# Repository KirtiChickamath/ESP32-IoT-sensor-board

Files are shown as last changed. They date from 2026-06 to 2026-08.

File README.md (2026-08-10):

# ESP32 IoT Sensor Board

A 4-layer IoT PCB designed in KiCad 9 as part of the **Advanced PCB Design with KiCad 9** course by Dr. Peter Dalmaris.

## Overview

This board is a medium-complexity IoT development platform built around the ESP32-C3 microcontroller. It includes power management, wireless connectivity, storage, and environmental sensing. All on a compact 4-layer PCB.

## Features

- ESP32-C3-WROOM-02 — WiFi and Bluetooth
- USB-C input with ESD protection (USBLC6) and polyfuse
- LiPo battery management with power-path (MCP73871)
- 3.3V LDO voltage regulator (LM1117)
- USB-to-UART bridge (CP2102N) for programming and debugging
- SPI flash memory (W25Q32)
- MicroSD card slot (SPI mode)
- BME280 — temperature, humidity, and pressure (I2C)
- Ambient light sensor (TEMT6000)
- Microphone with preamplifier (MAX4466)
- Status LEDs — power good, charging, charged
- Boot and EN tactile switches
- GPIO and I2C breakout header
- Test points for SPI signals

## Layer Stackup

 Layer - Purpose 

 Top copper - L1 -  Components and signal routing 
 Inner 1 - L2 - Ground plane 
 Inner 2 - L3 - 3.3V power plane 
 Bottom copper - L4 -  Additional signal routing 

## Communication Interfaces

 Interface - Connected To 

 SPI - Flash memory, SD card 
 I2C - BME280, OLED header 
 UART - CP2102N (via USB) 
 ADC - Light sensor, microphone 

## Schematic

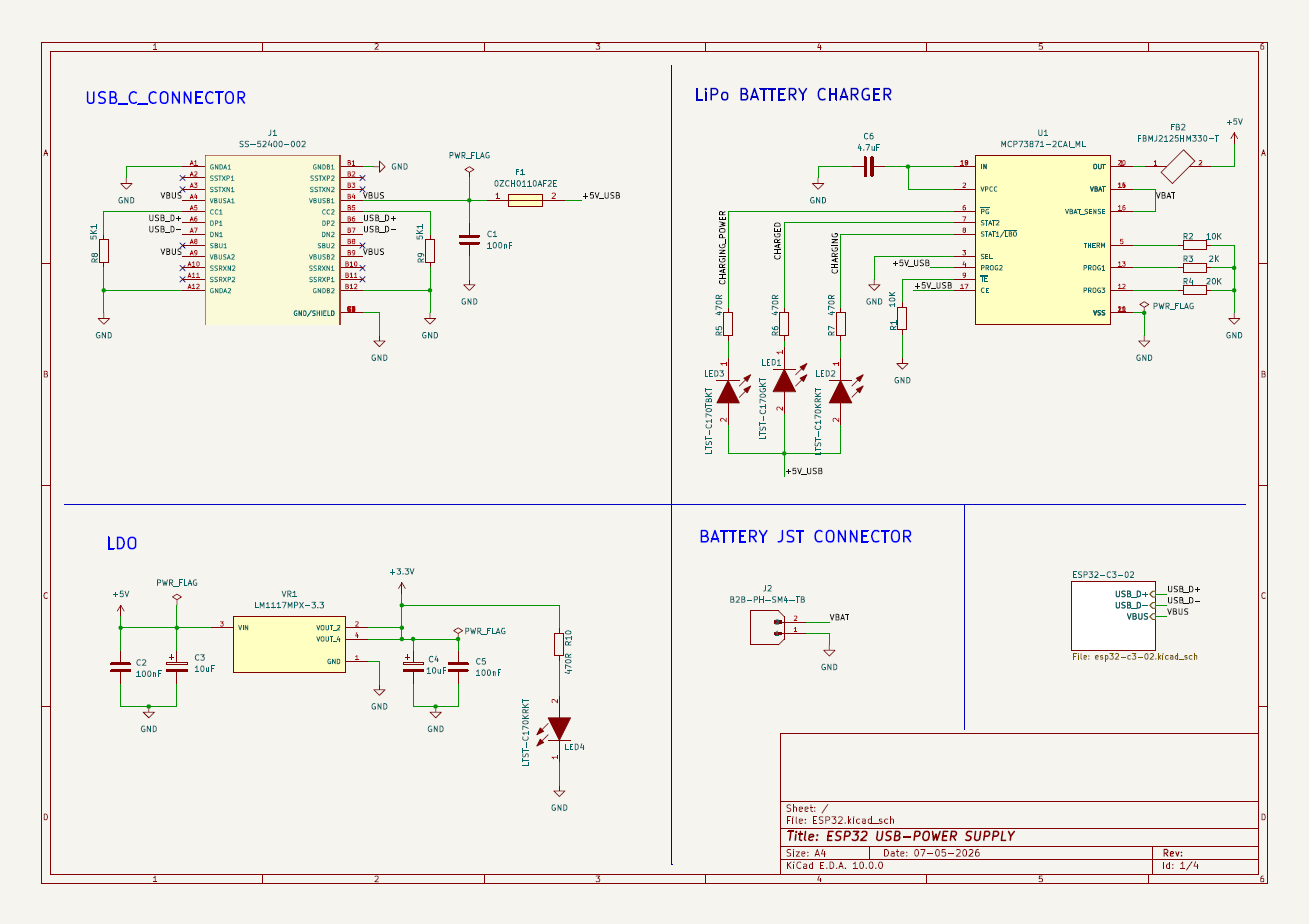
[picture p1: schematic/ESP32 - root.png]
Root

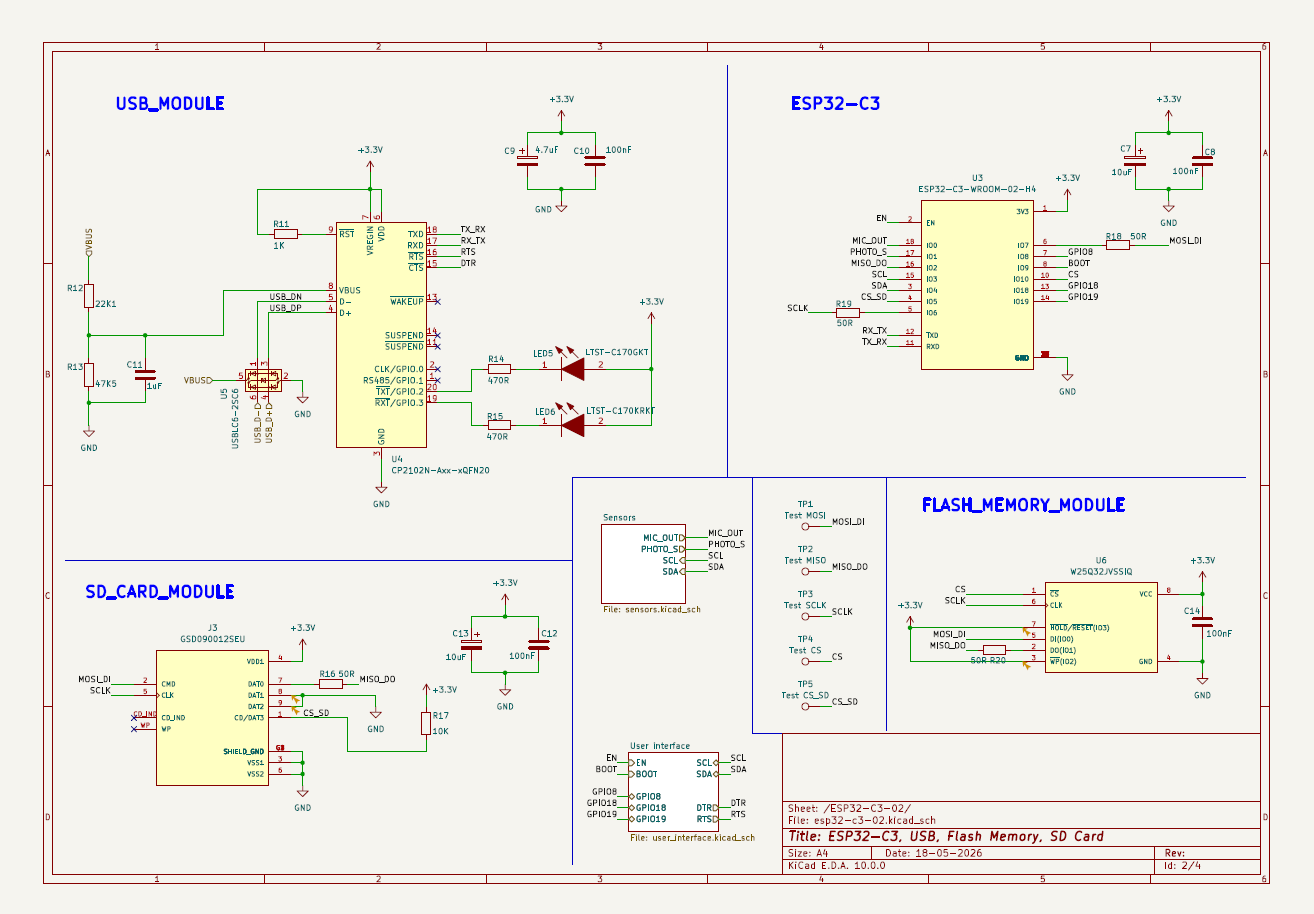
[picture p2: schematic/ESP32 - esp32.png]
ESP32

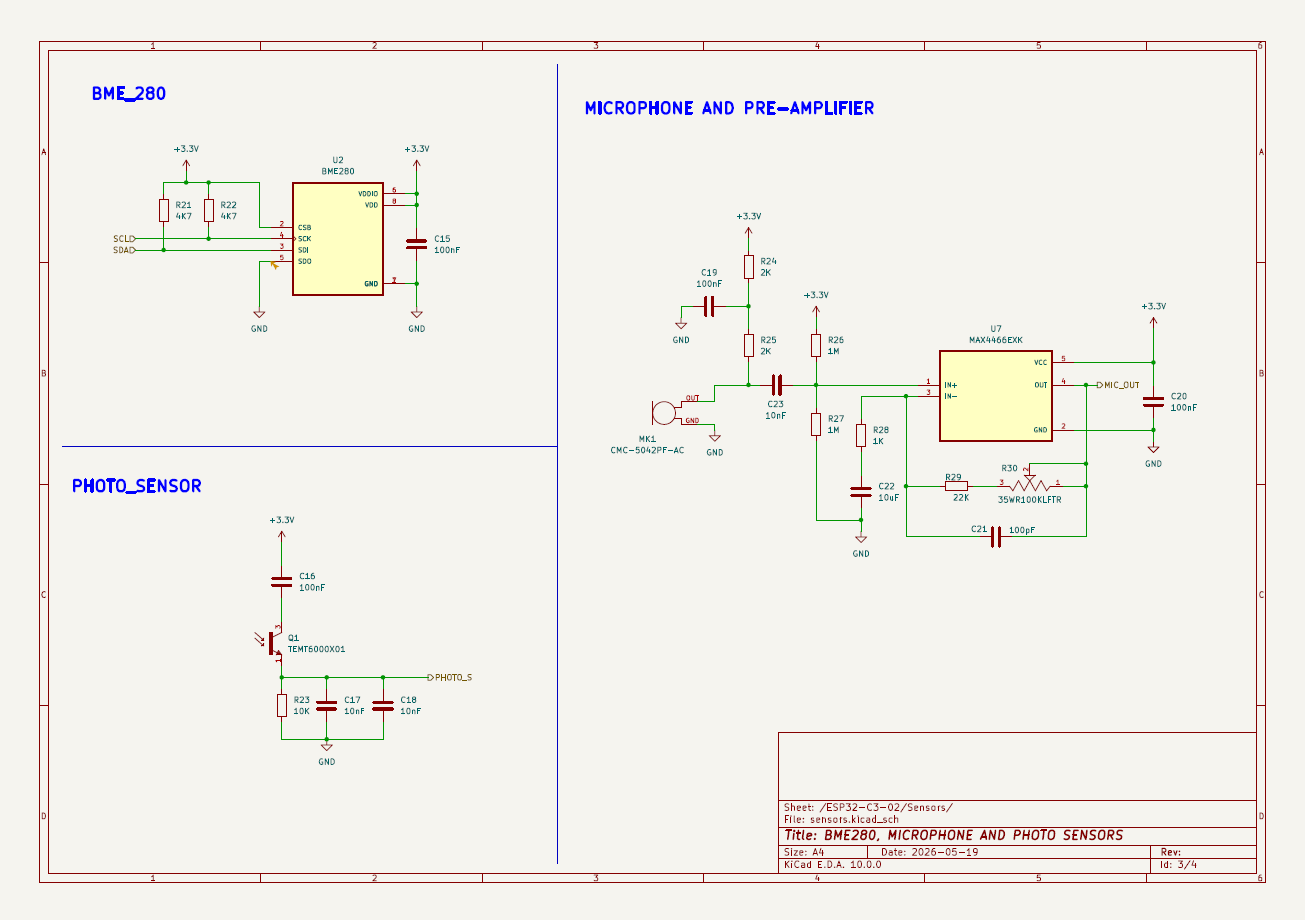
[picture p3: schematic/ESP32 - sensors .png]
Sensors

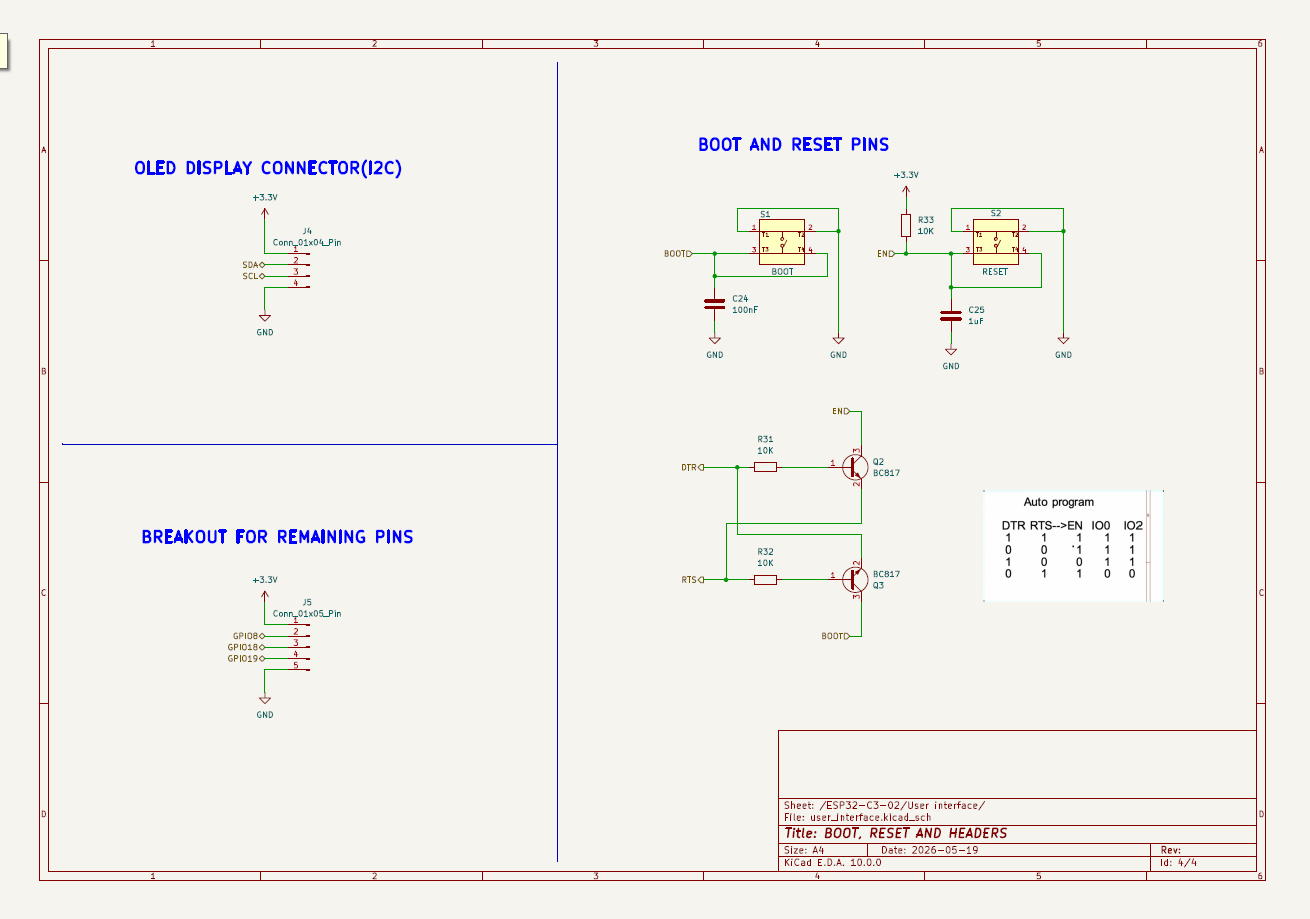
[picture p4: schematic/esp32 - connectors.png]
Connectors

---

## PCB Layout

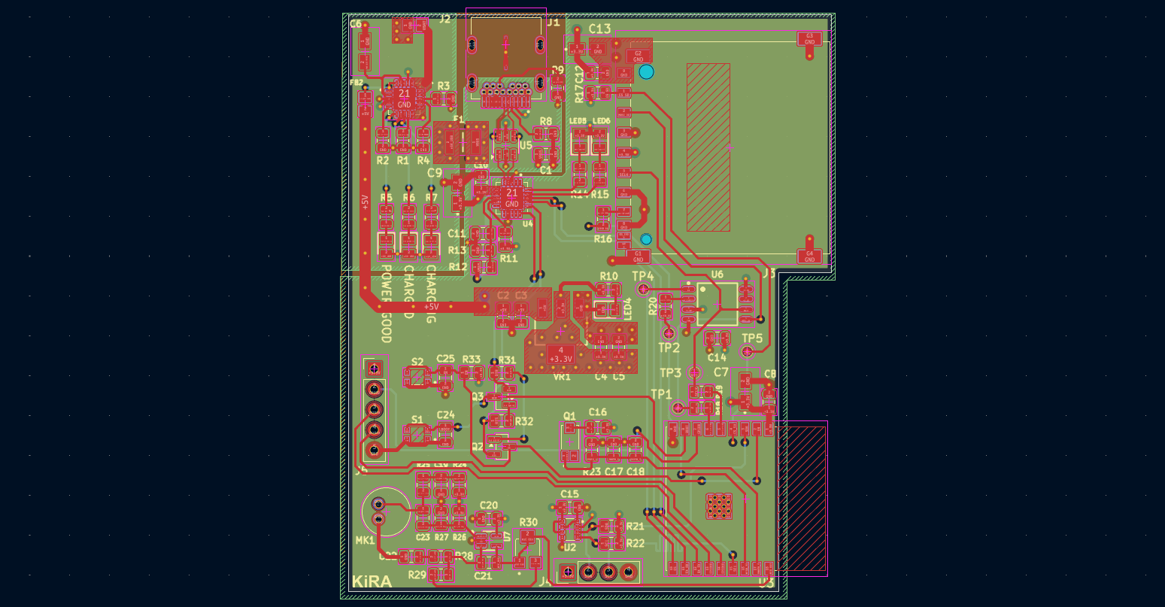
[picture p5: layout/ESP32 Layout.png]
Layout


## 3D View

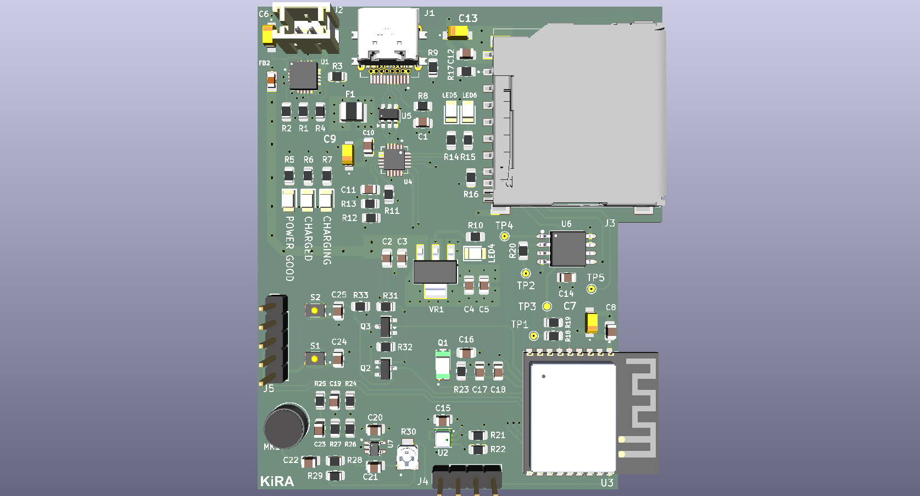
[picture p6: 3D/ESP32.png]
3D View


## Tools Used

- KiCad 
- HQDFM

---

## Course Reference

**Advanced PCB Design with KiCad 9**  
Instructor: Dr. Peter Dalmaris  
Platform: Udemy

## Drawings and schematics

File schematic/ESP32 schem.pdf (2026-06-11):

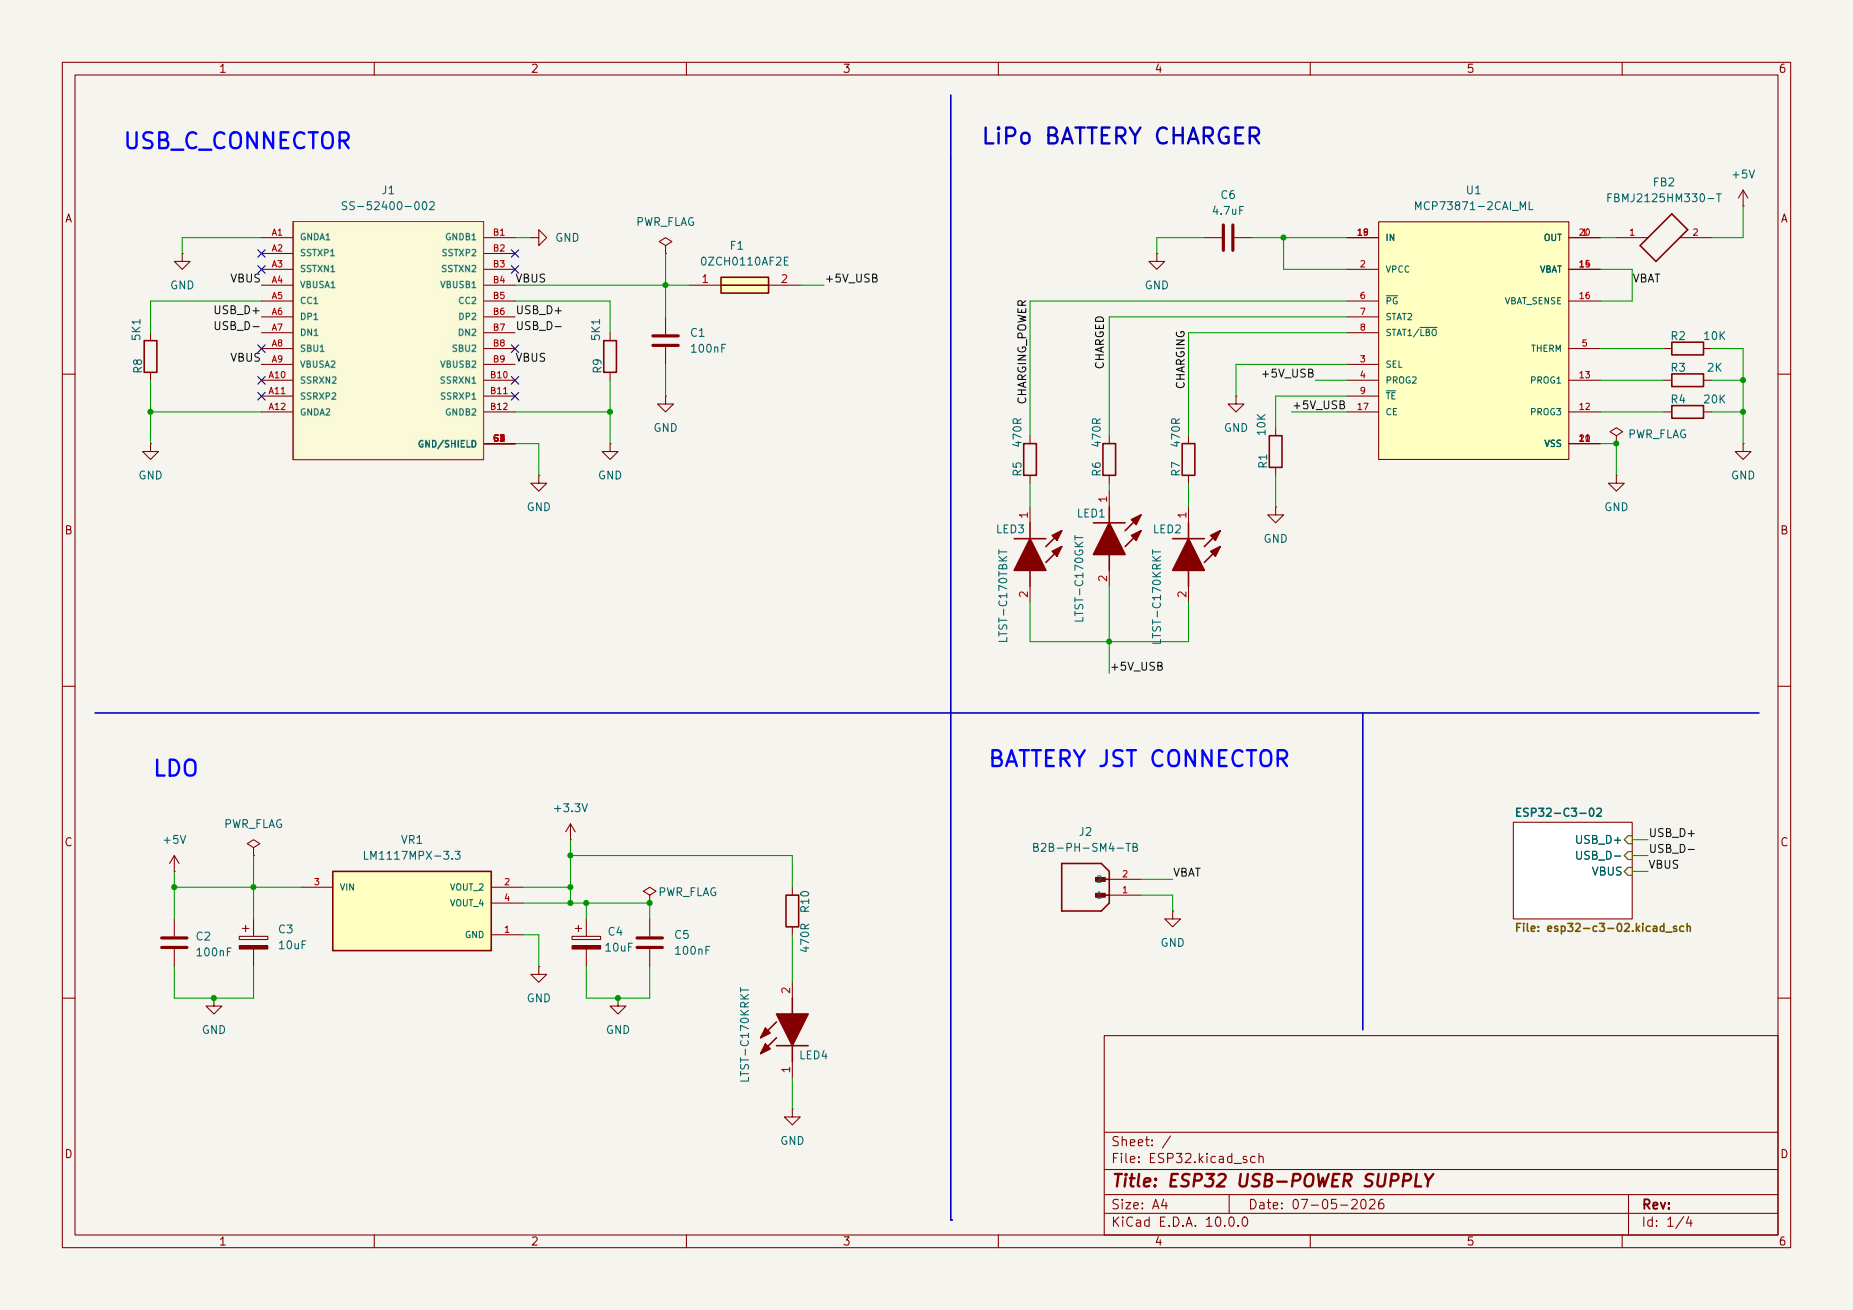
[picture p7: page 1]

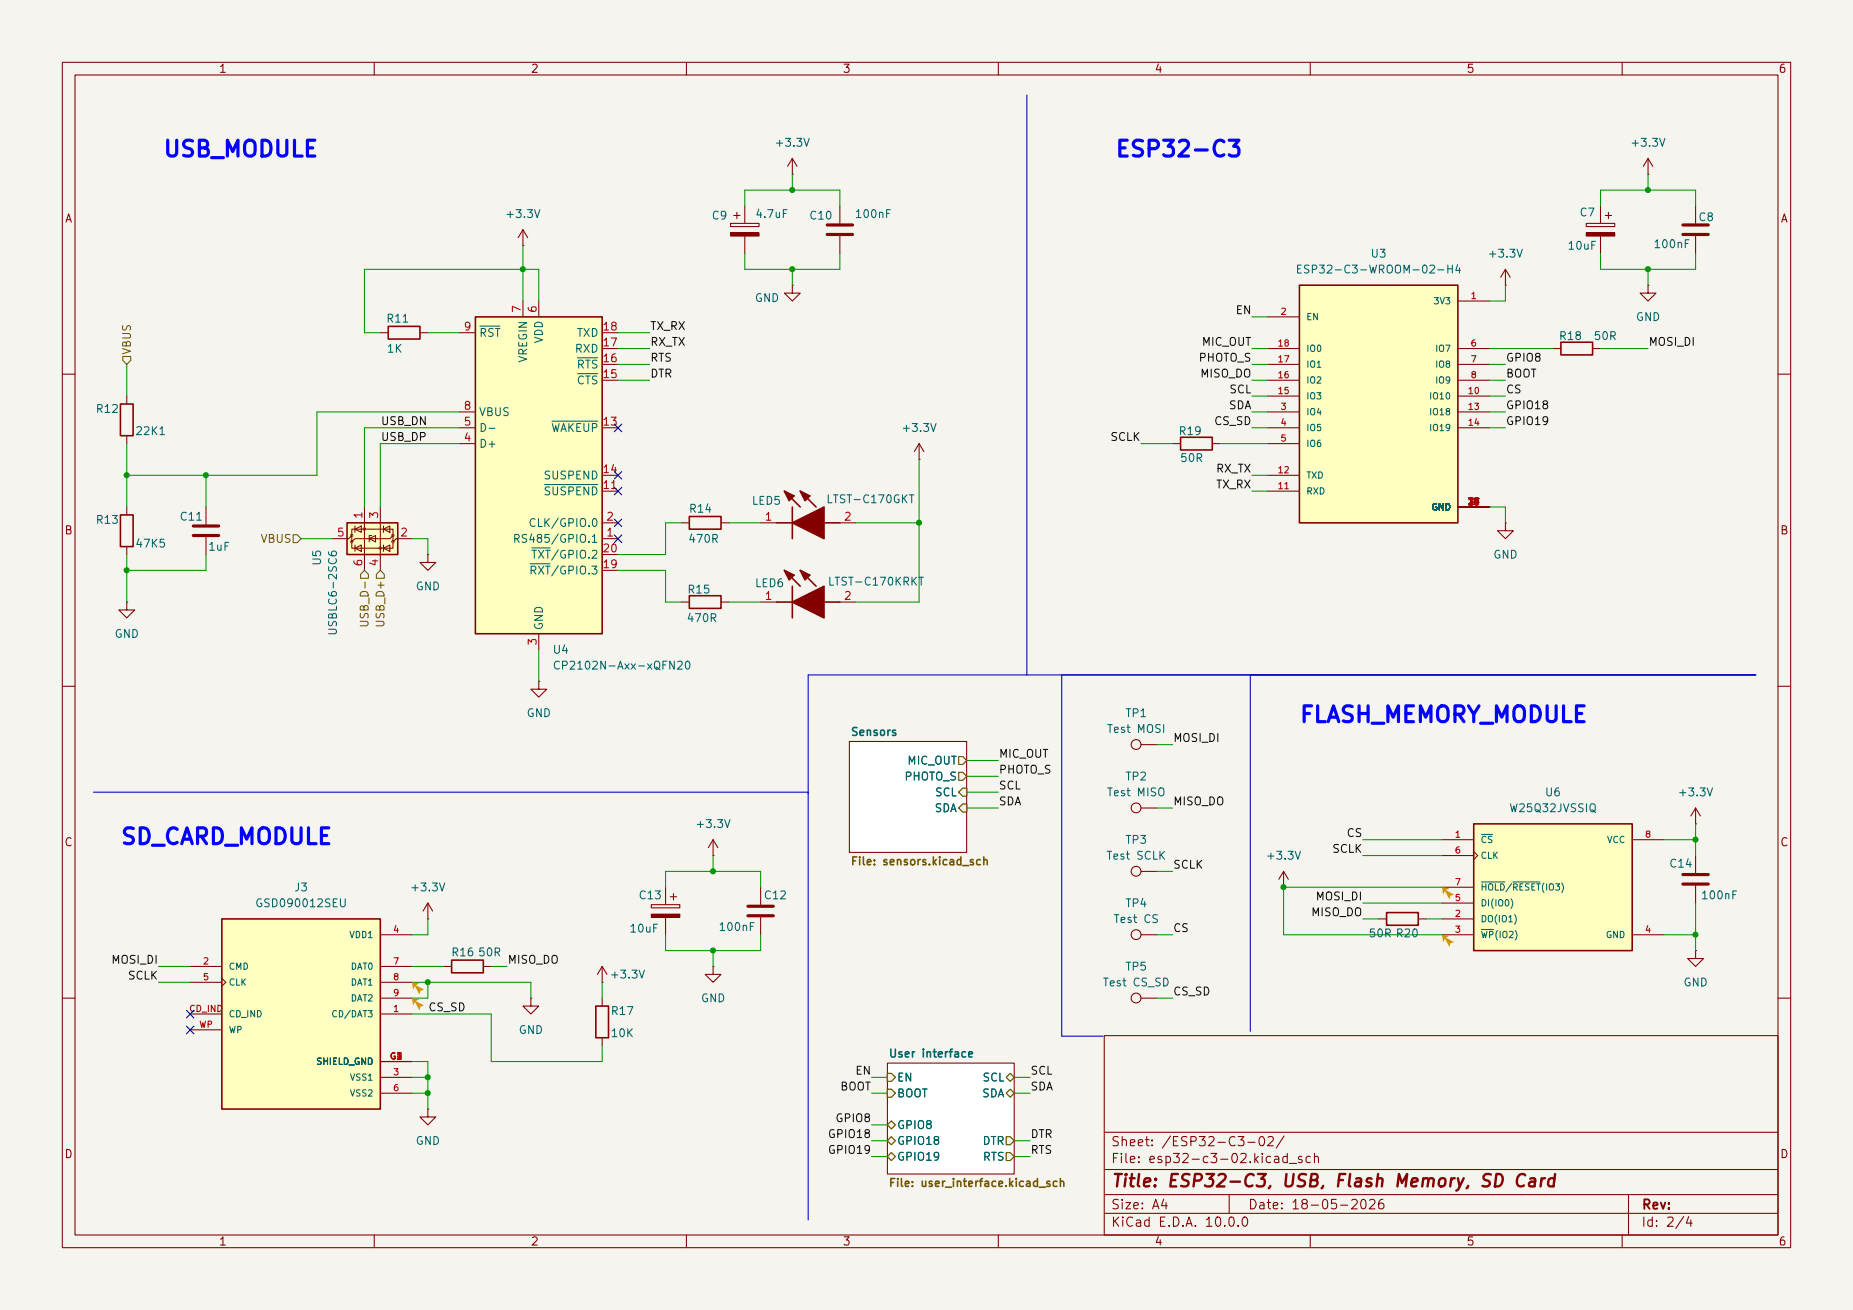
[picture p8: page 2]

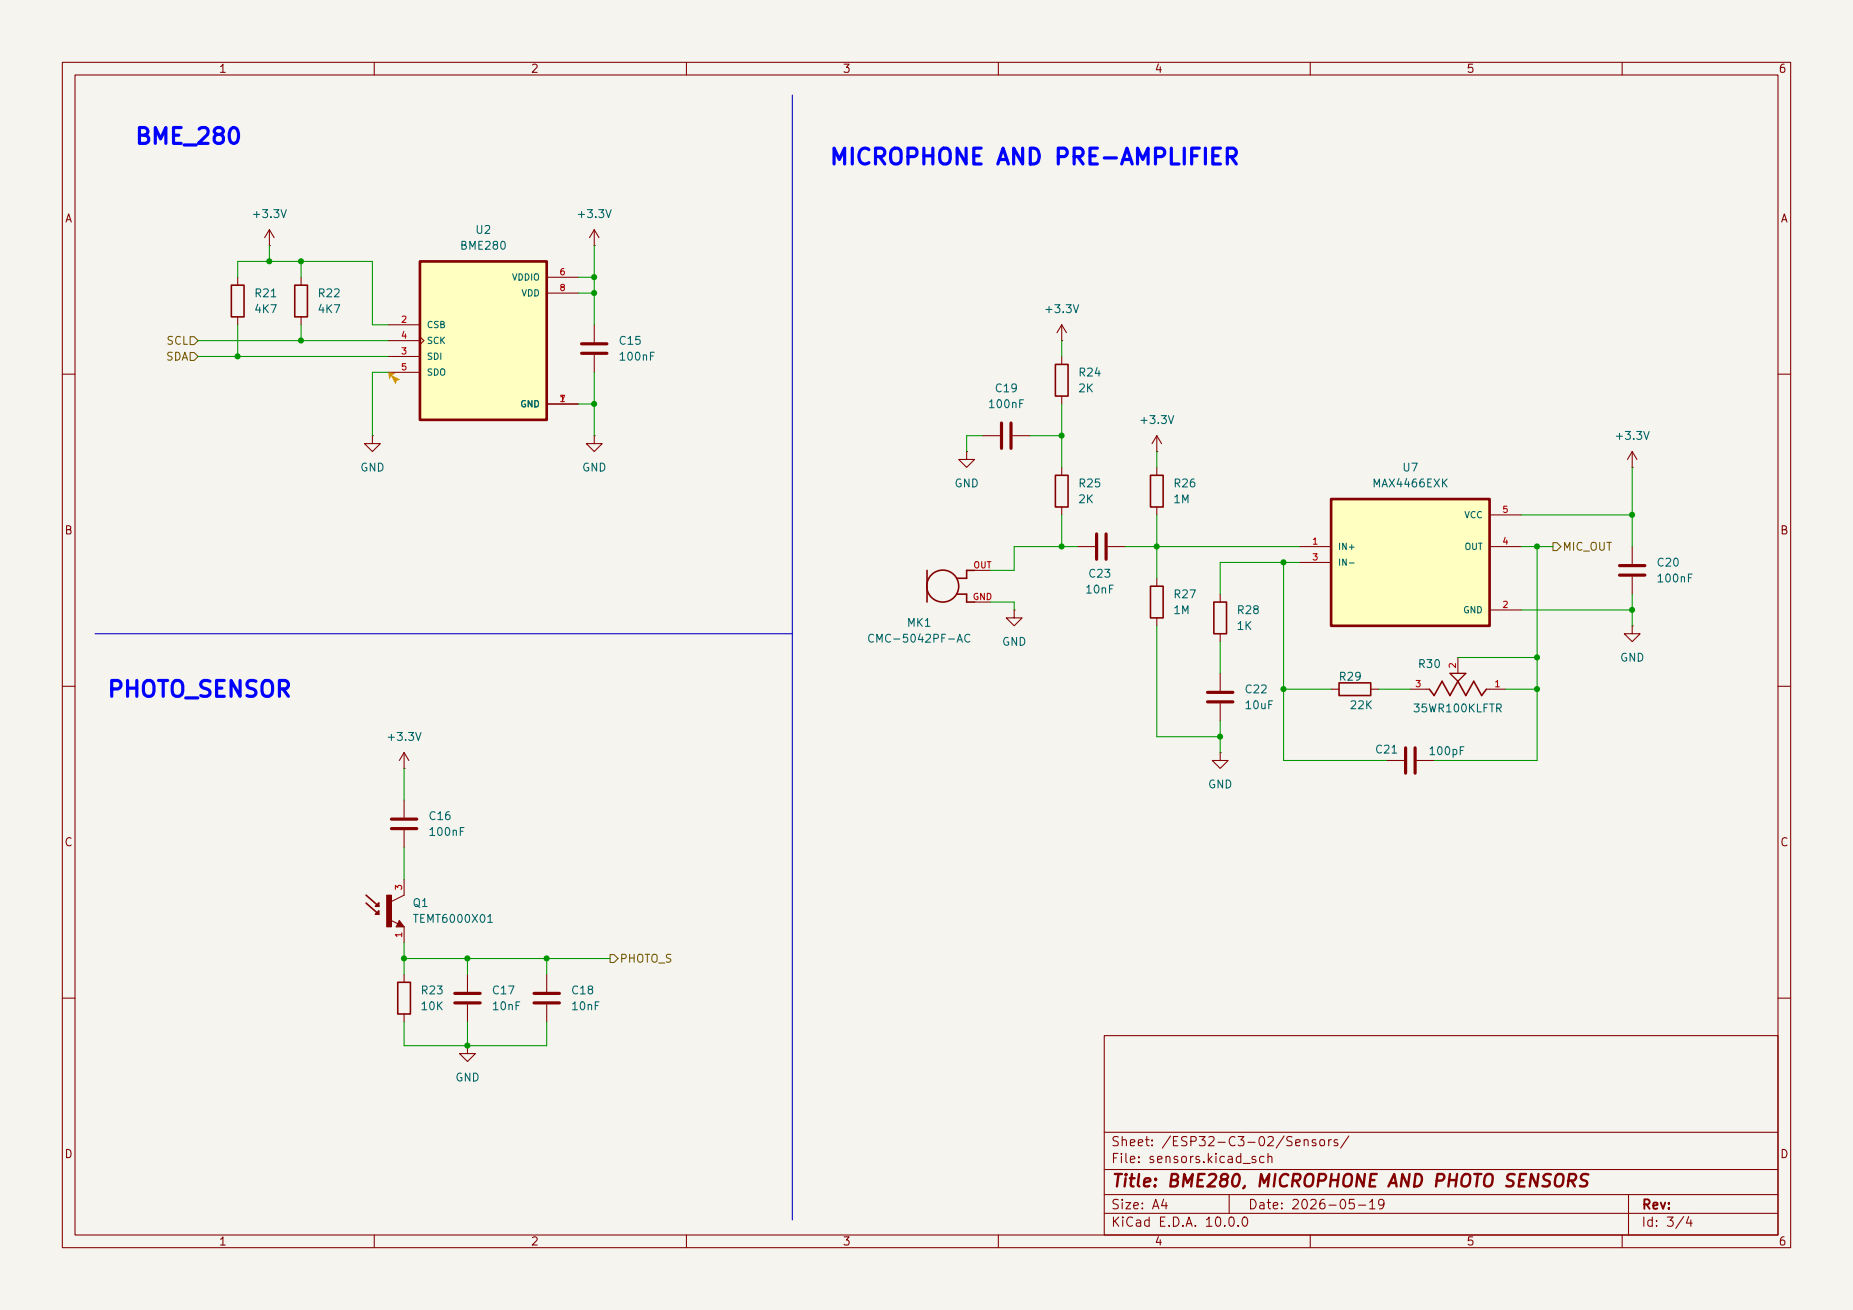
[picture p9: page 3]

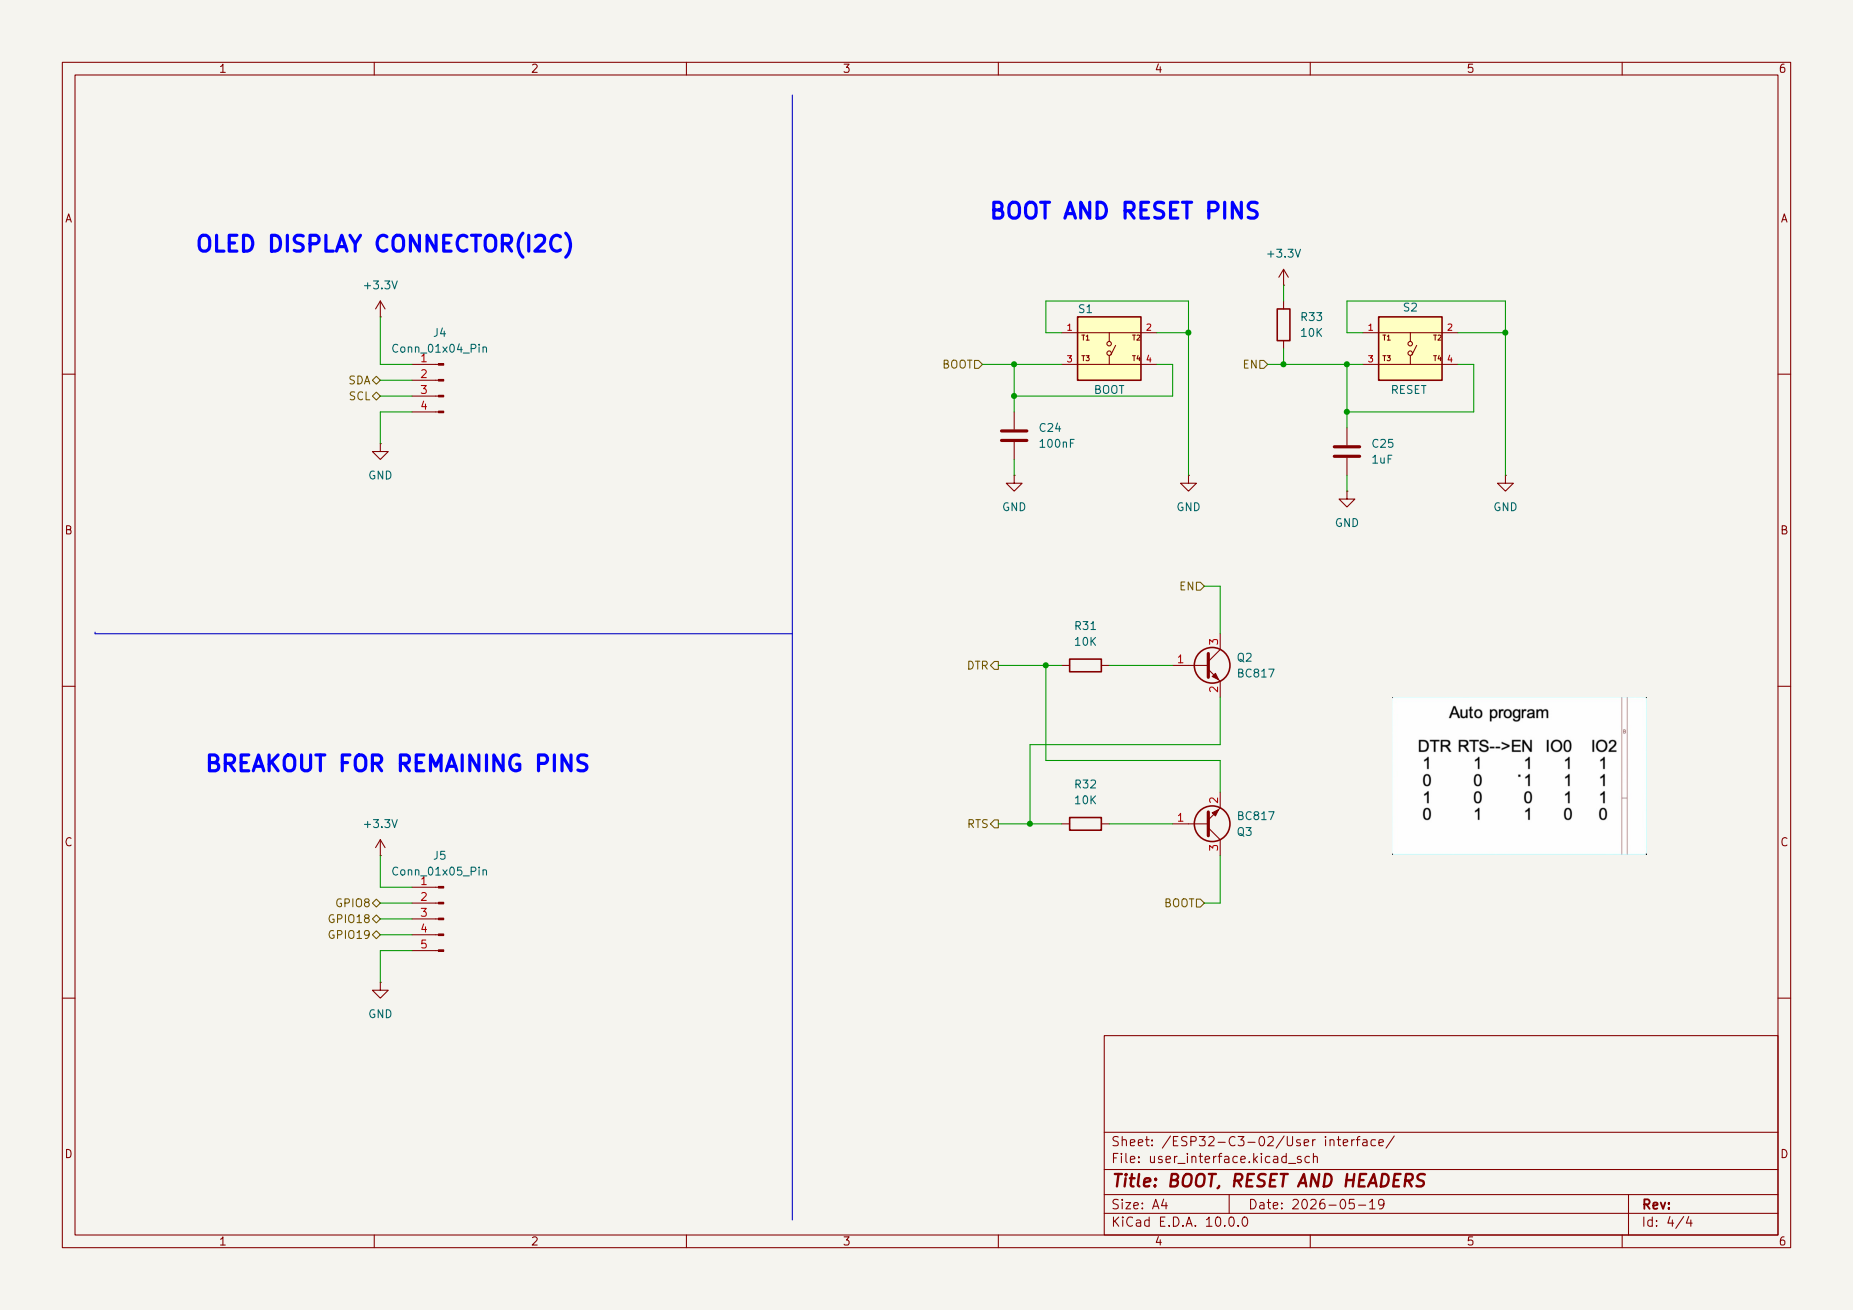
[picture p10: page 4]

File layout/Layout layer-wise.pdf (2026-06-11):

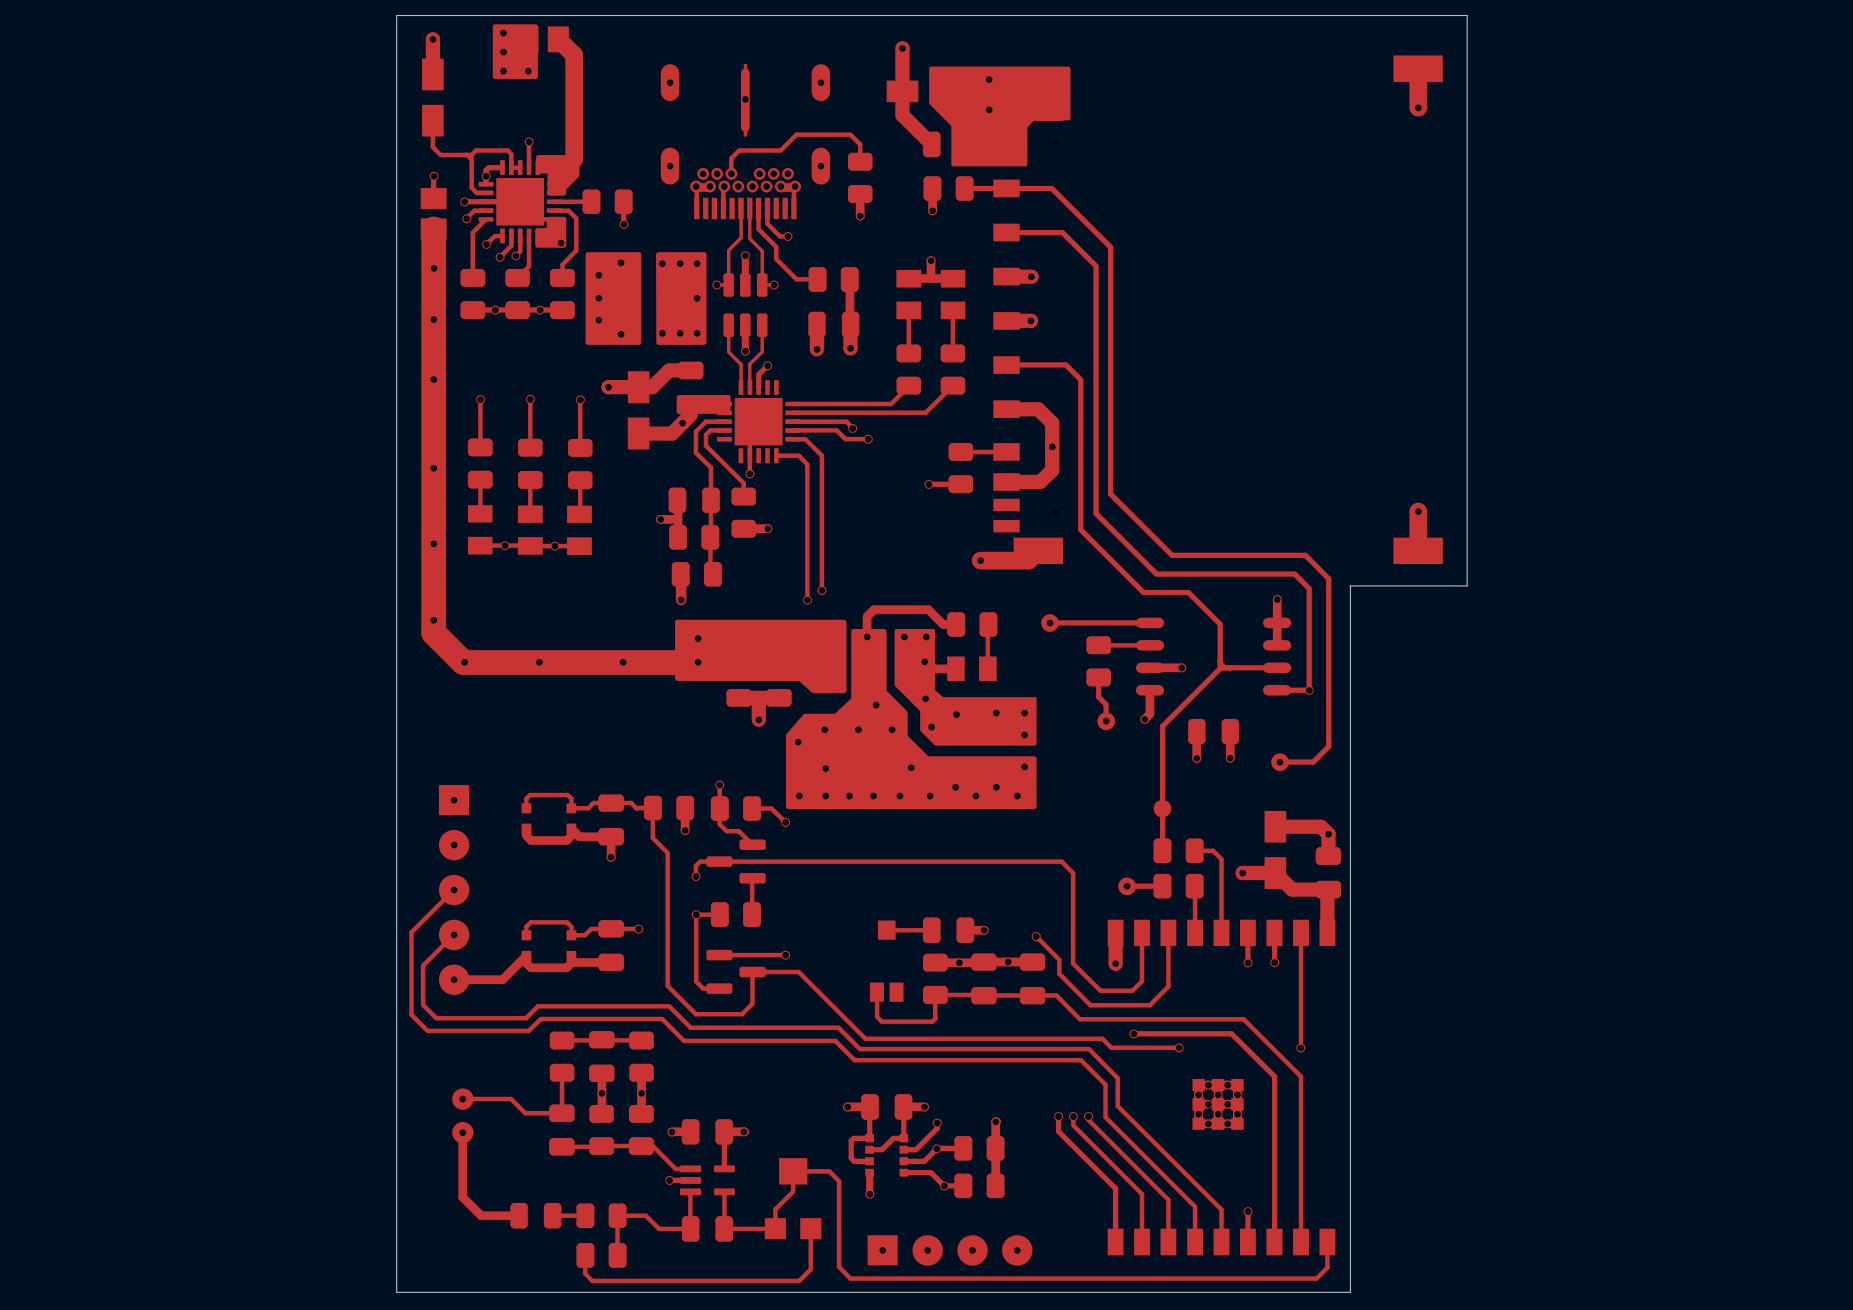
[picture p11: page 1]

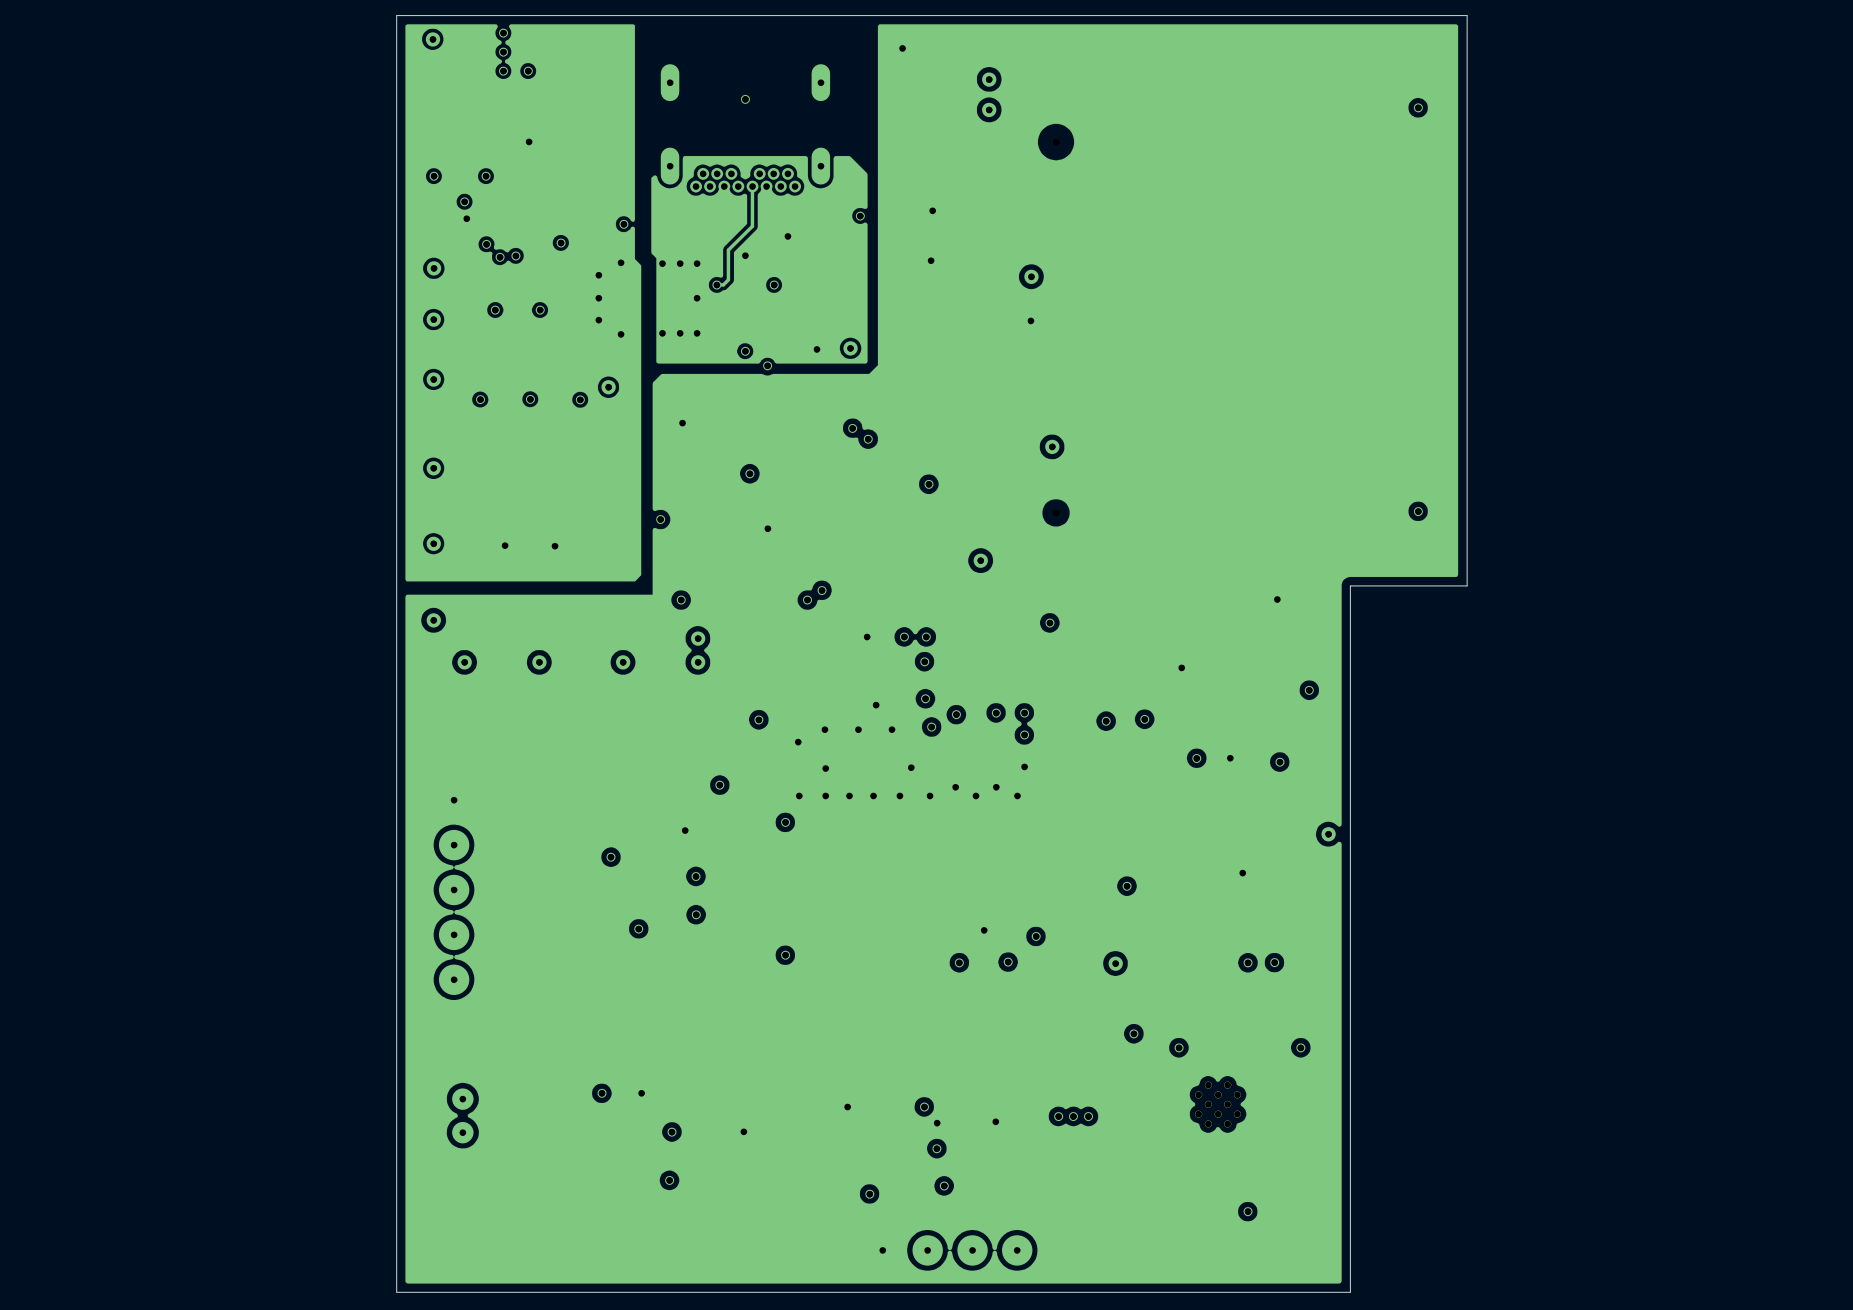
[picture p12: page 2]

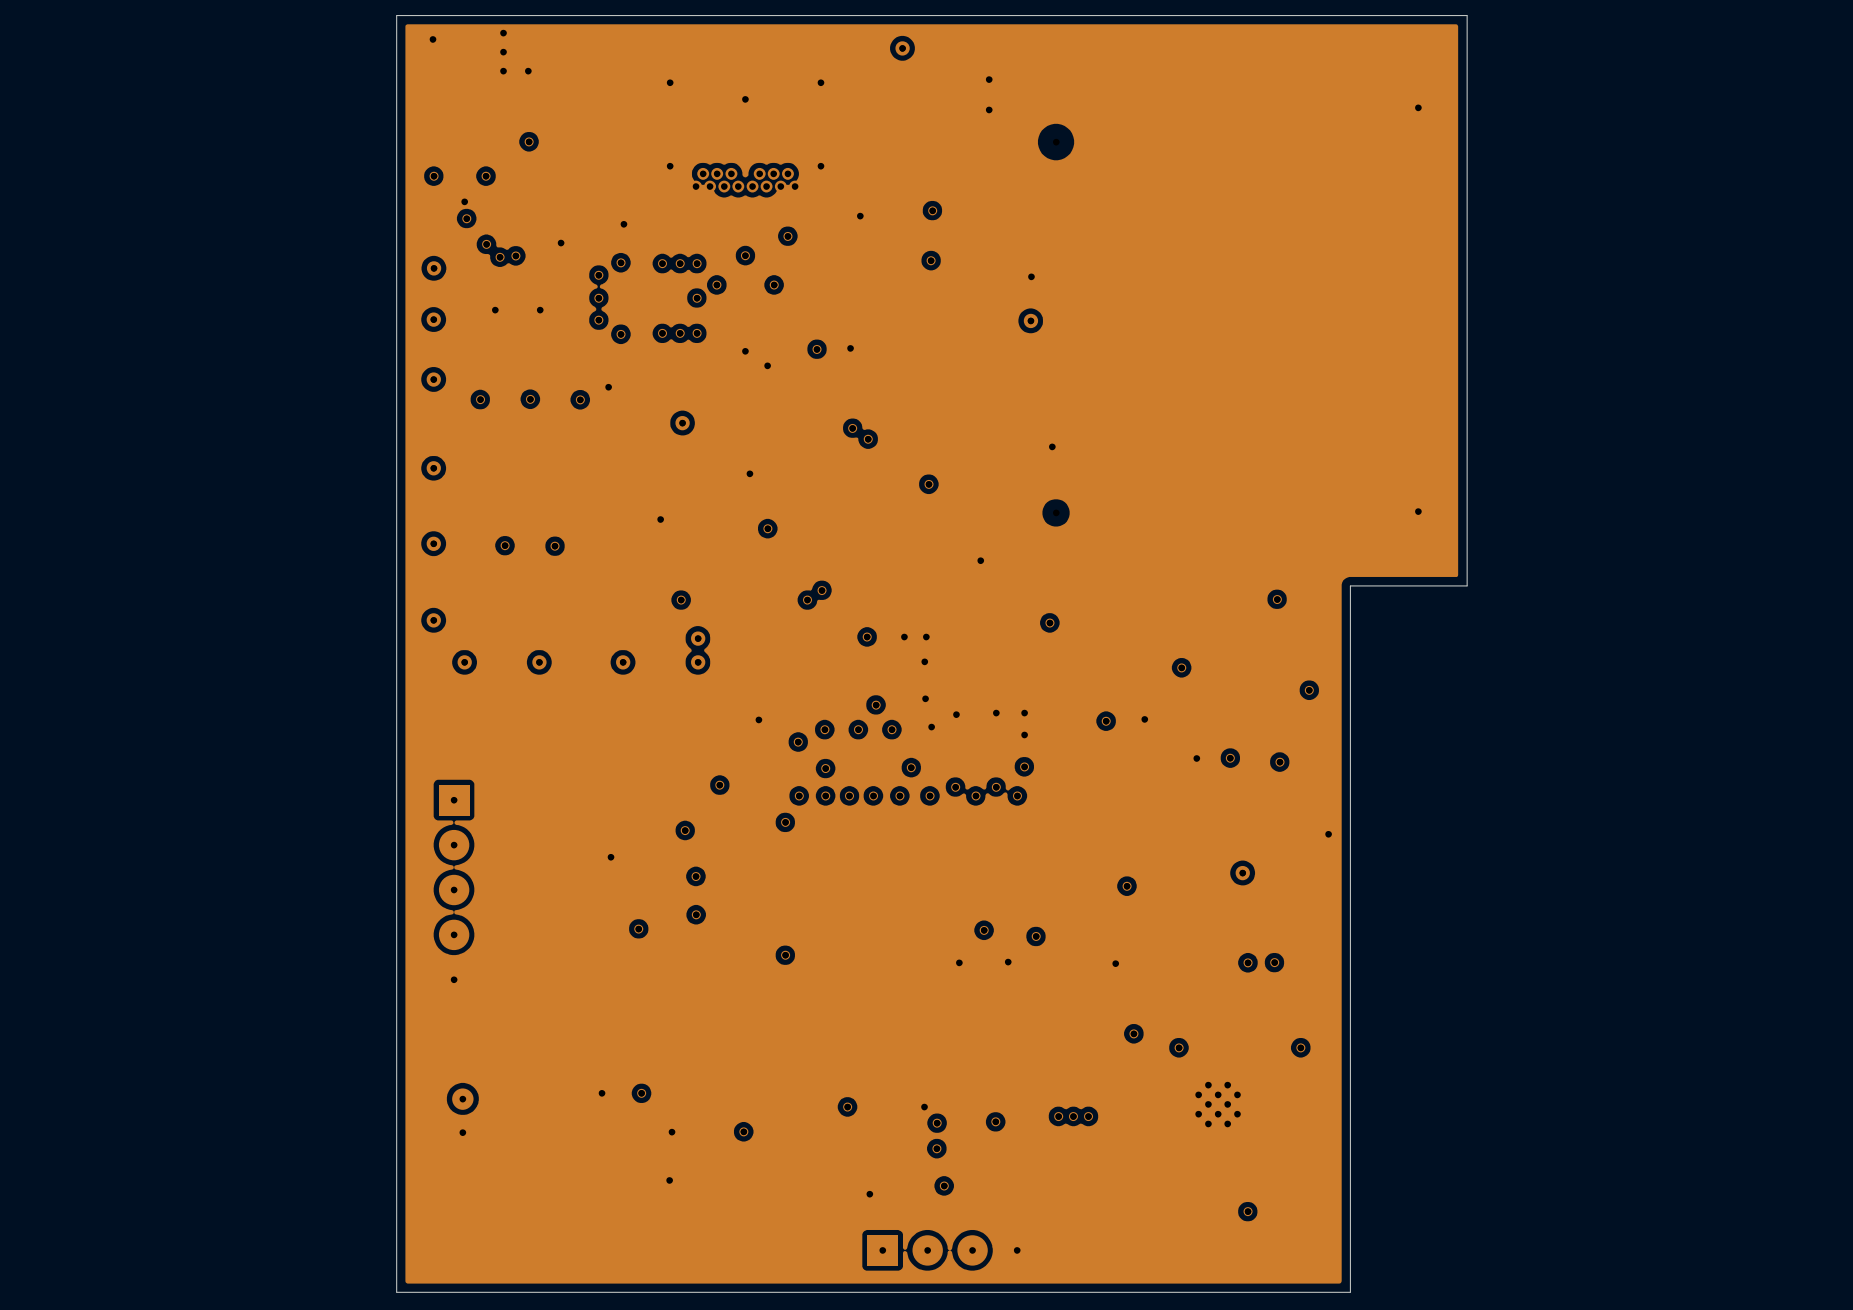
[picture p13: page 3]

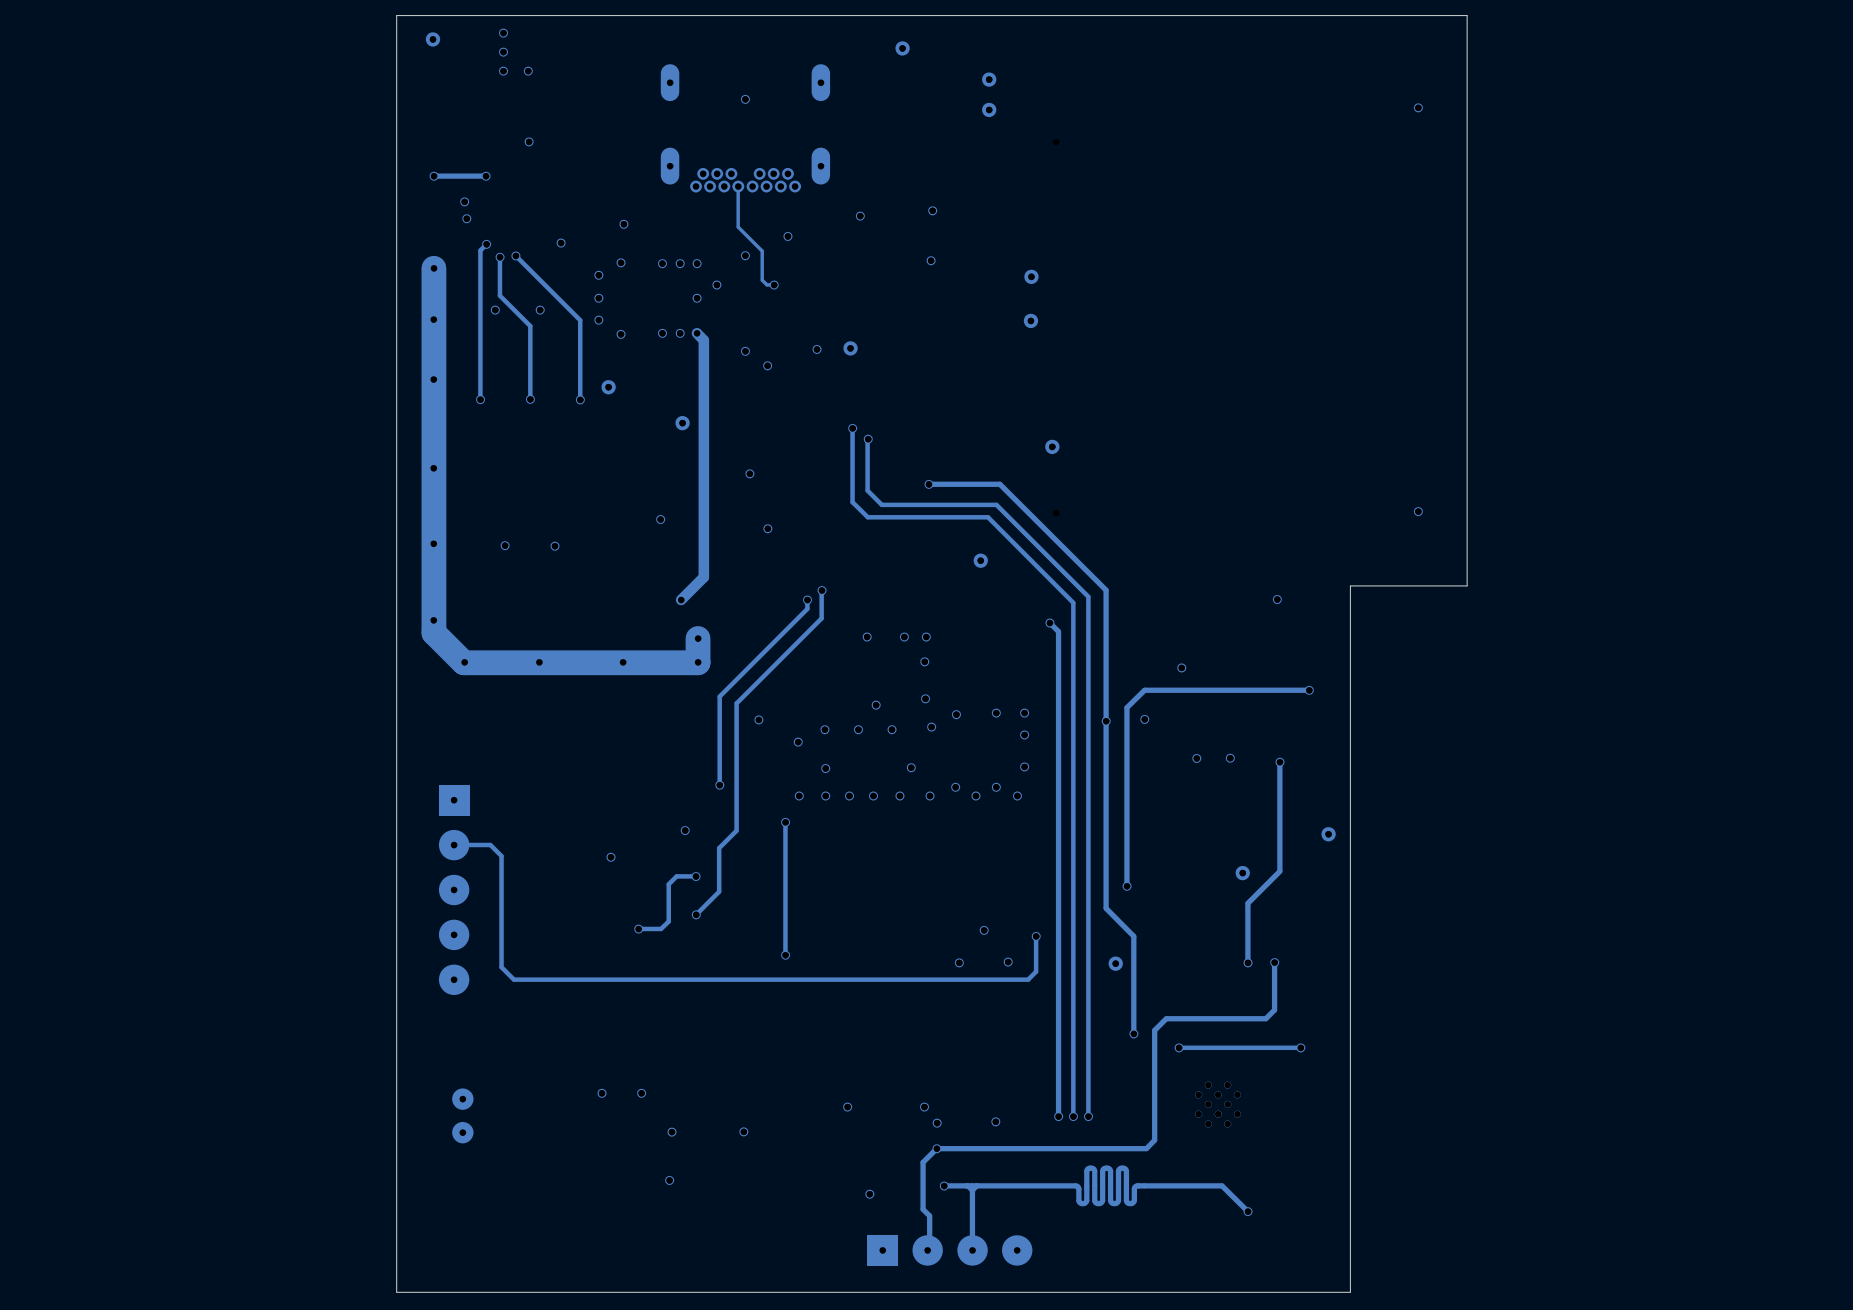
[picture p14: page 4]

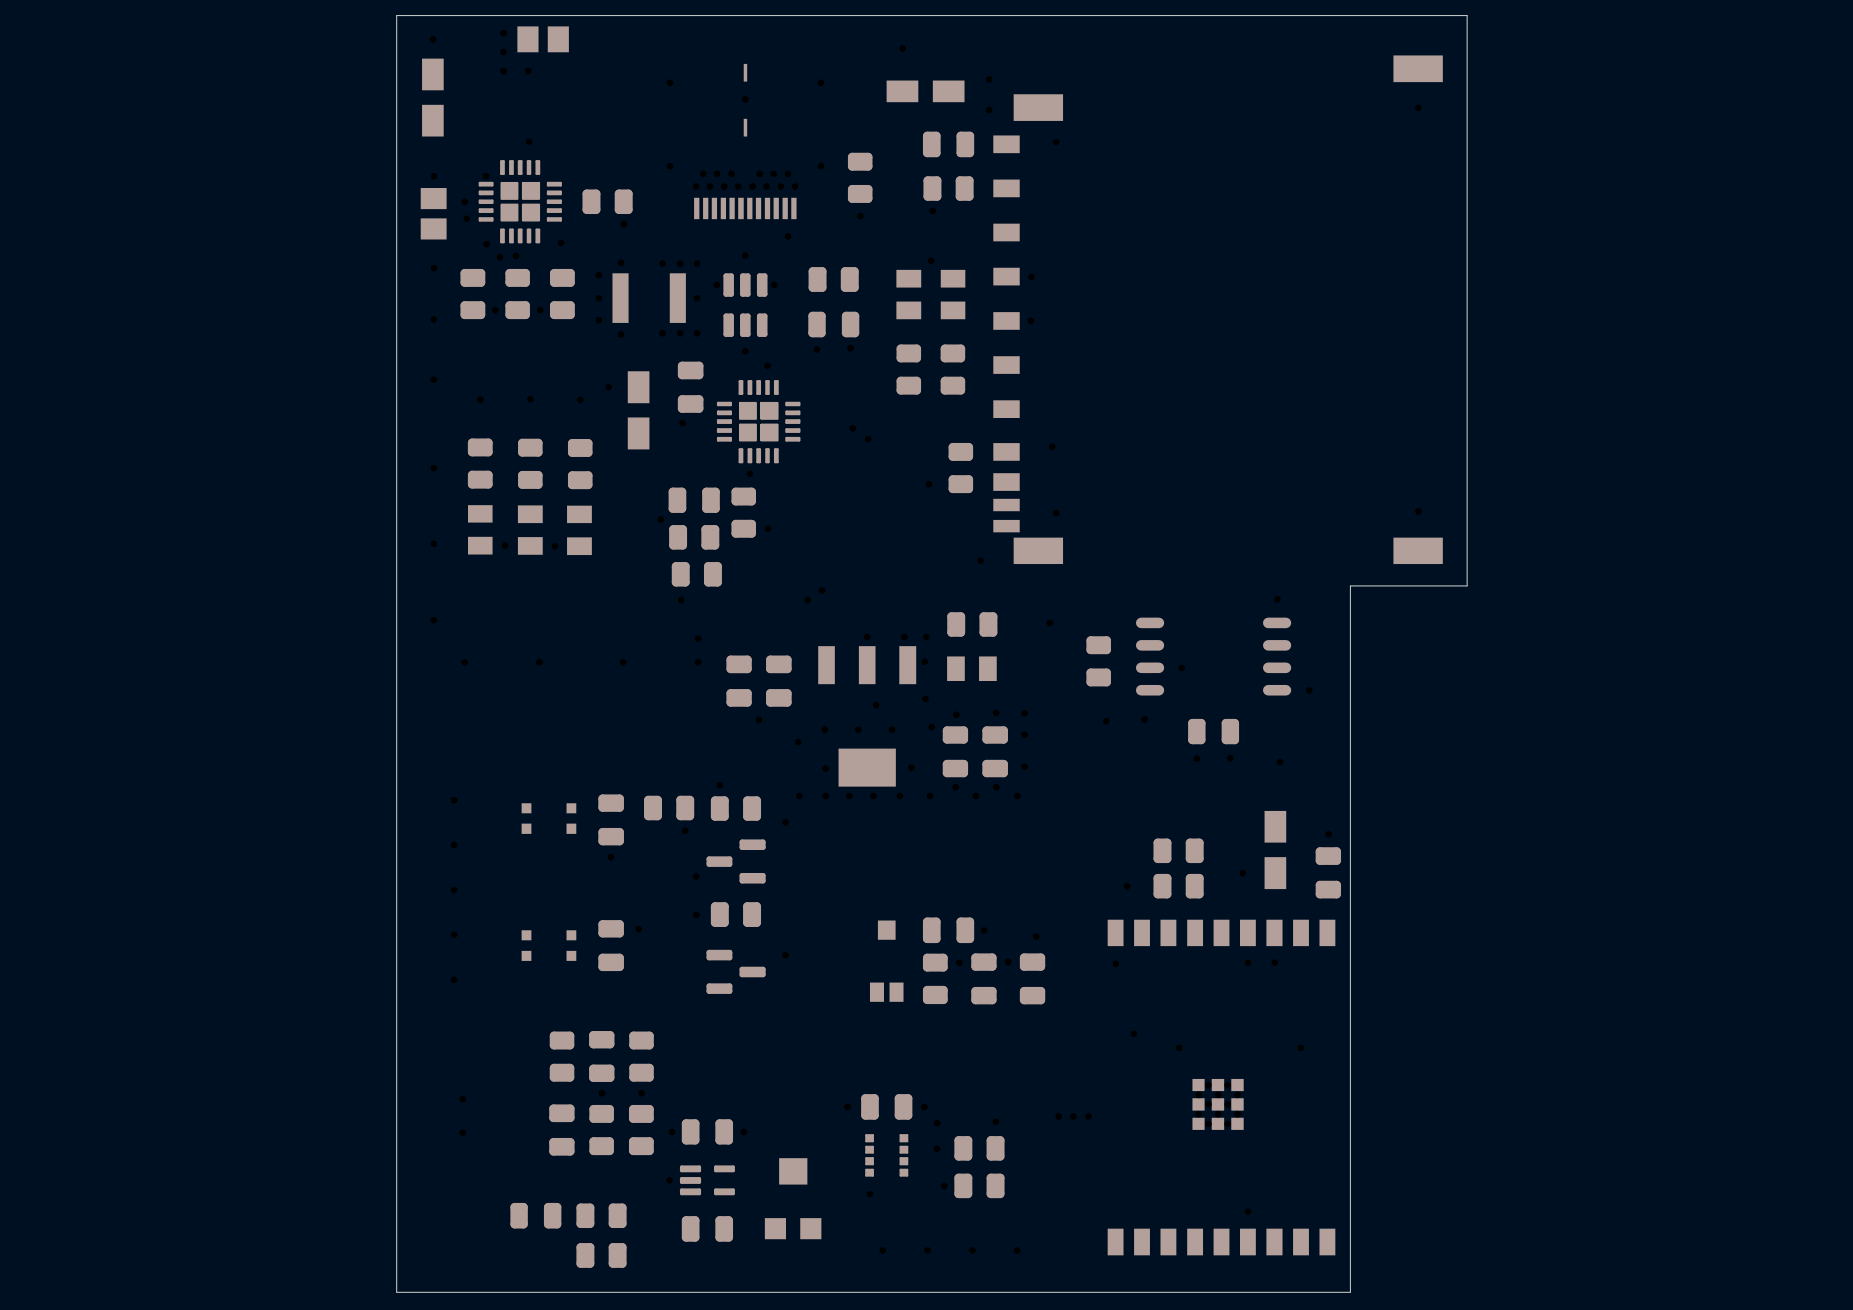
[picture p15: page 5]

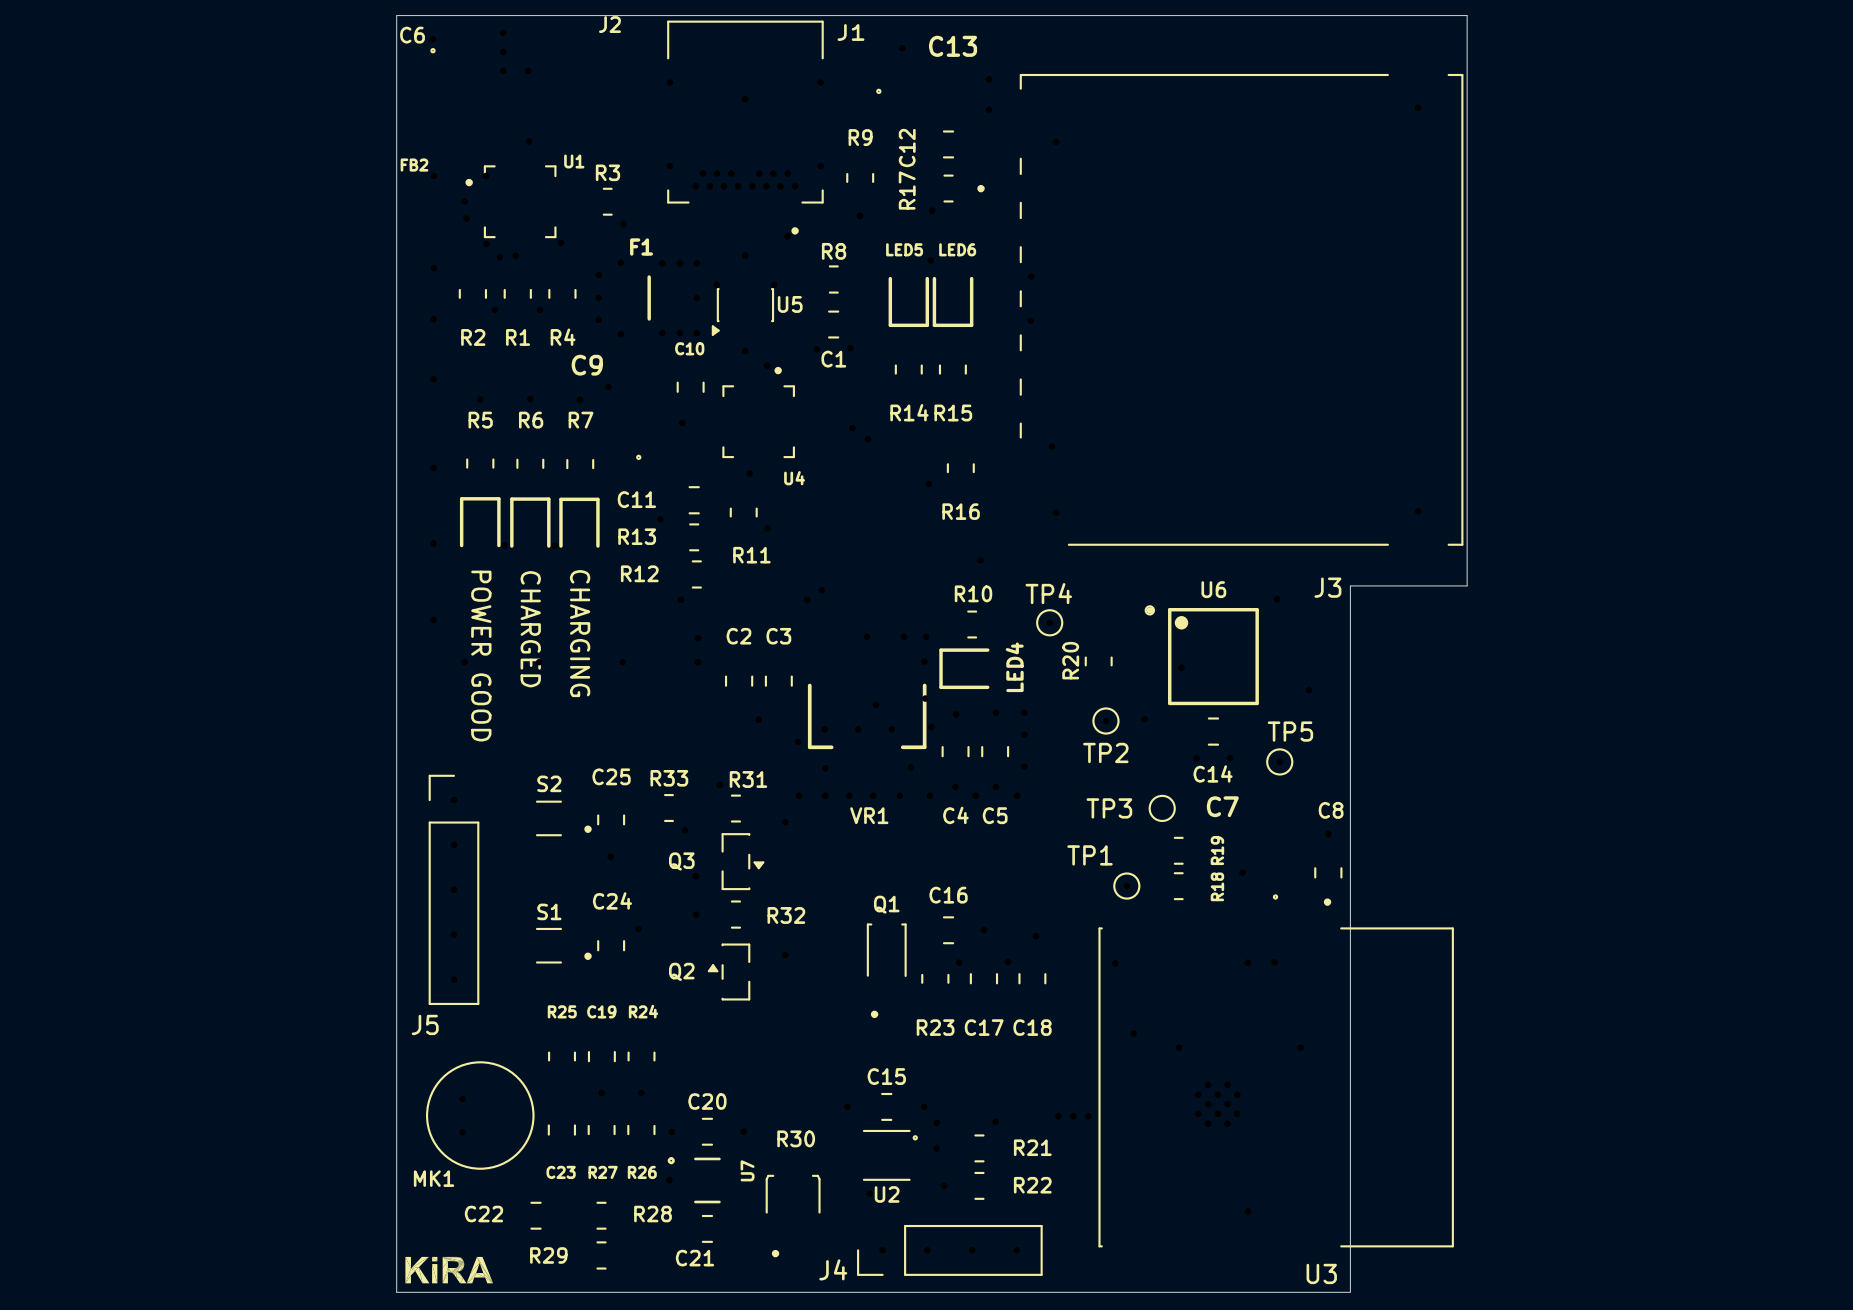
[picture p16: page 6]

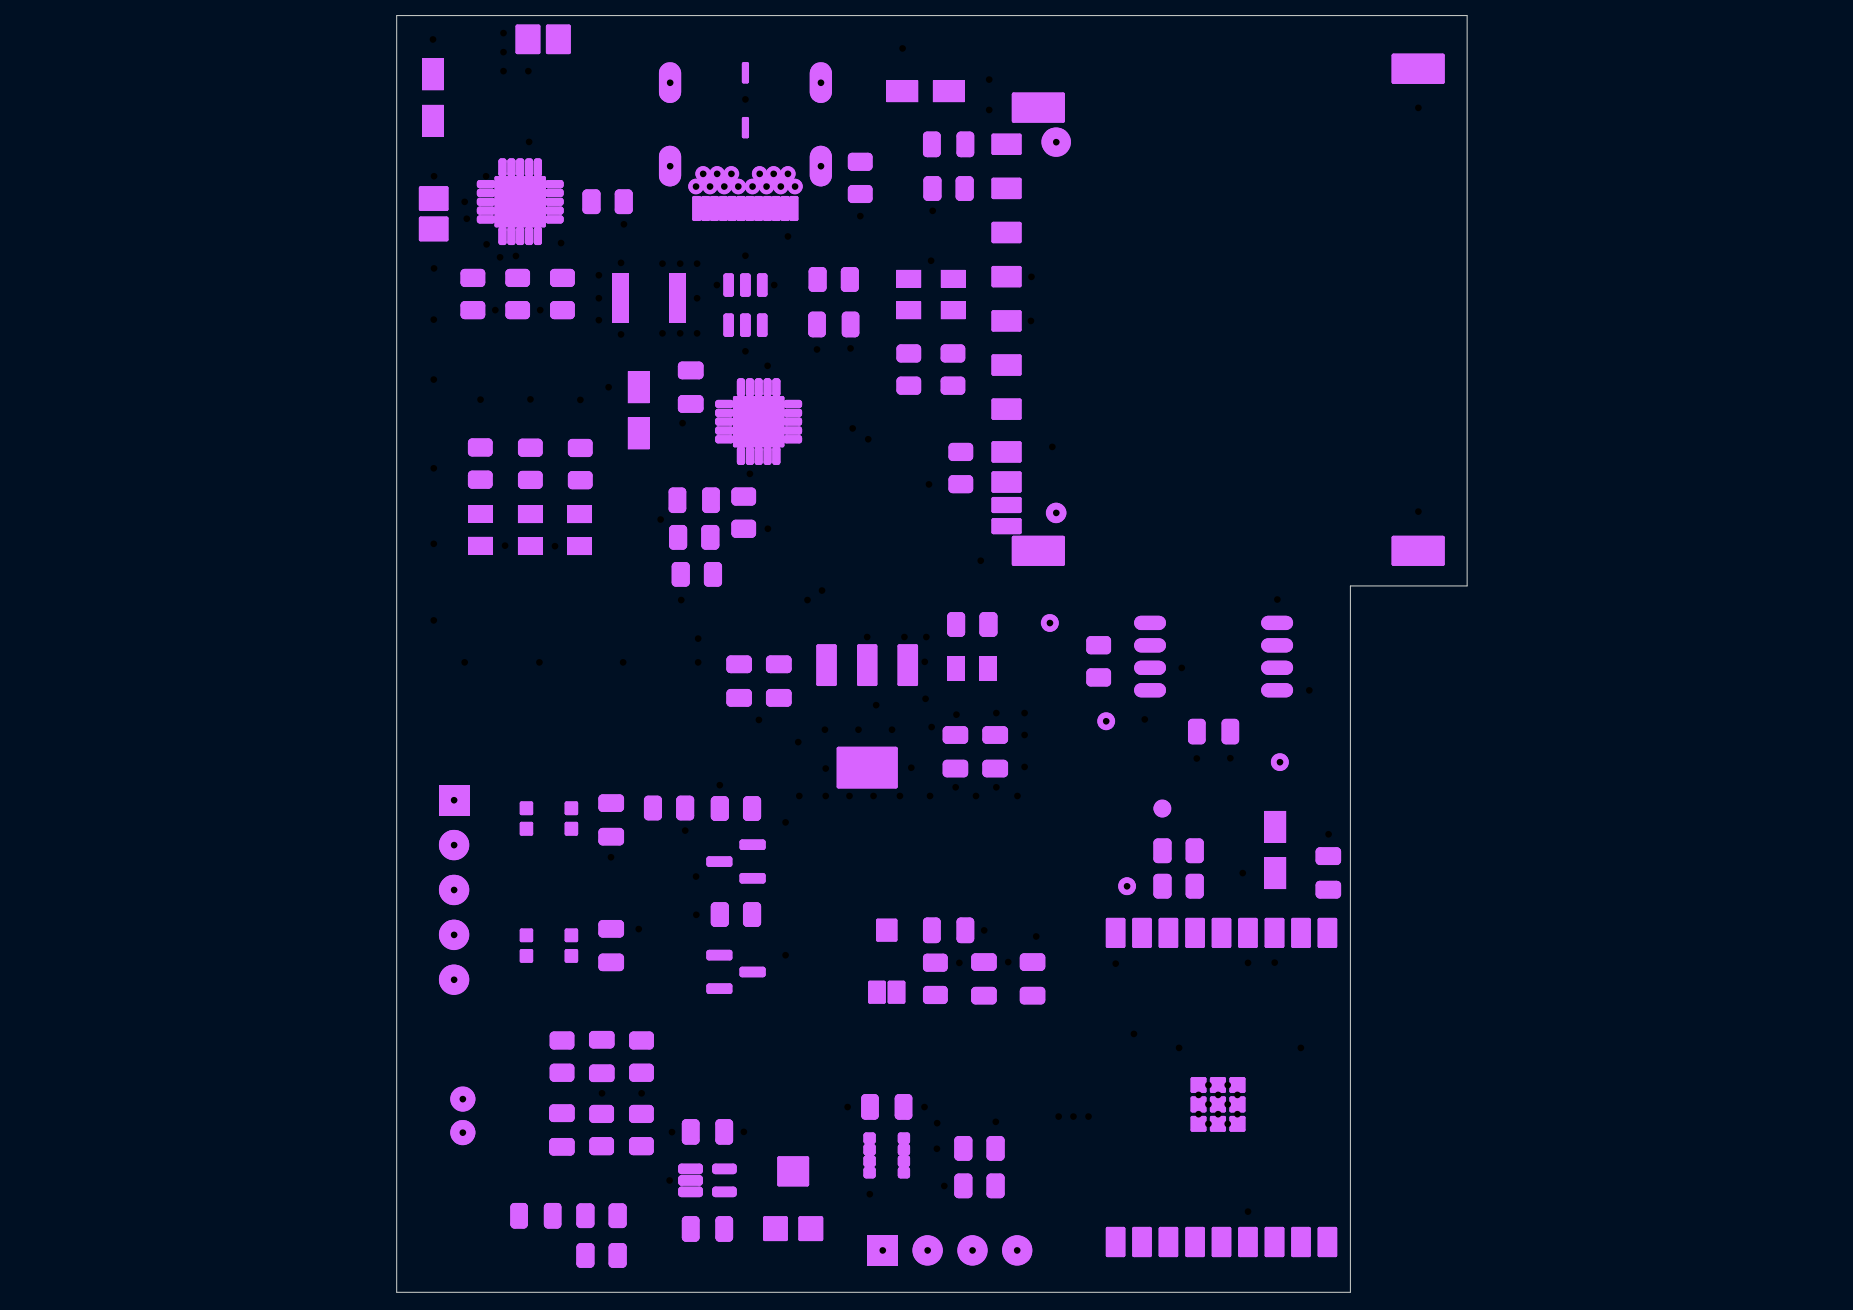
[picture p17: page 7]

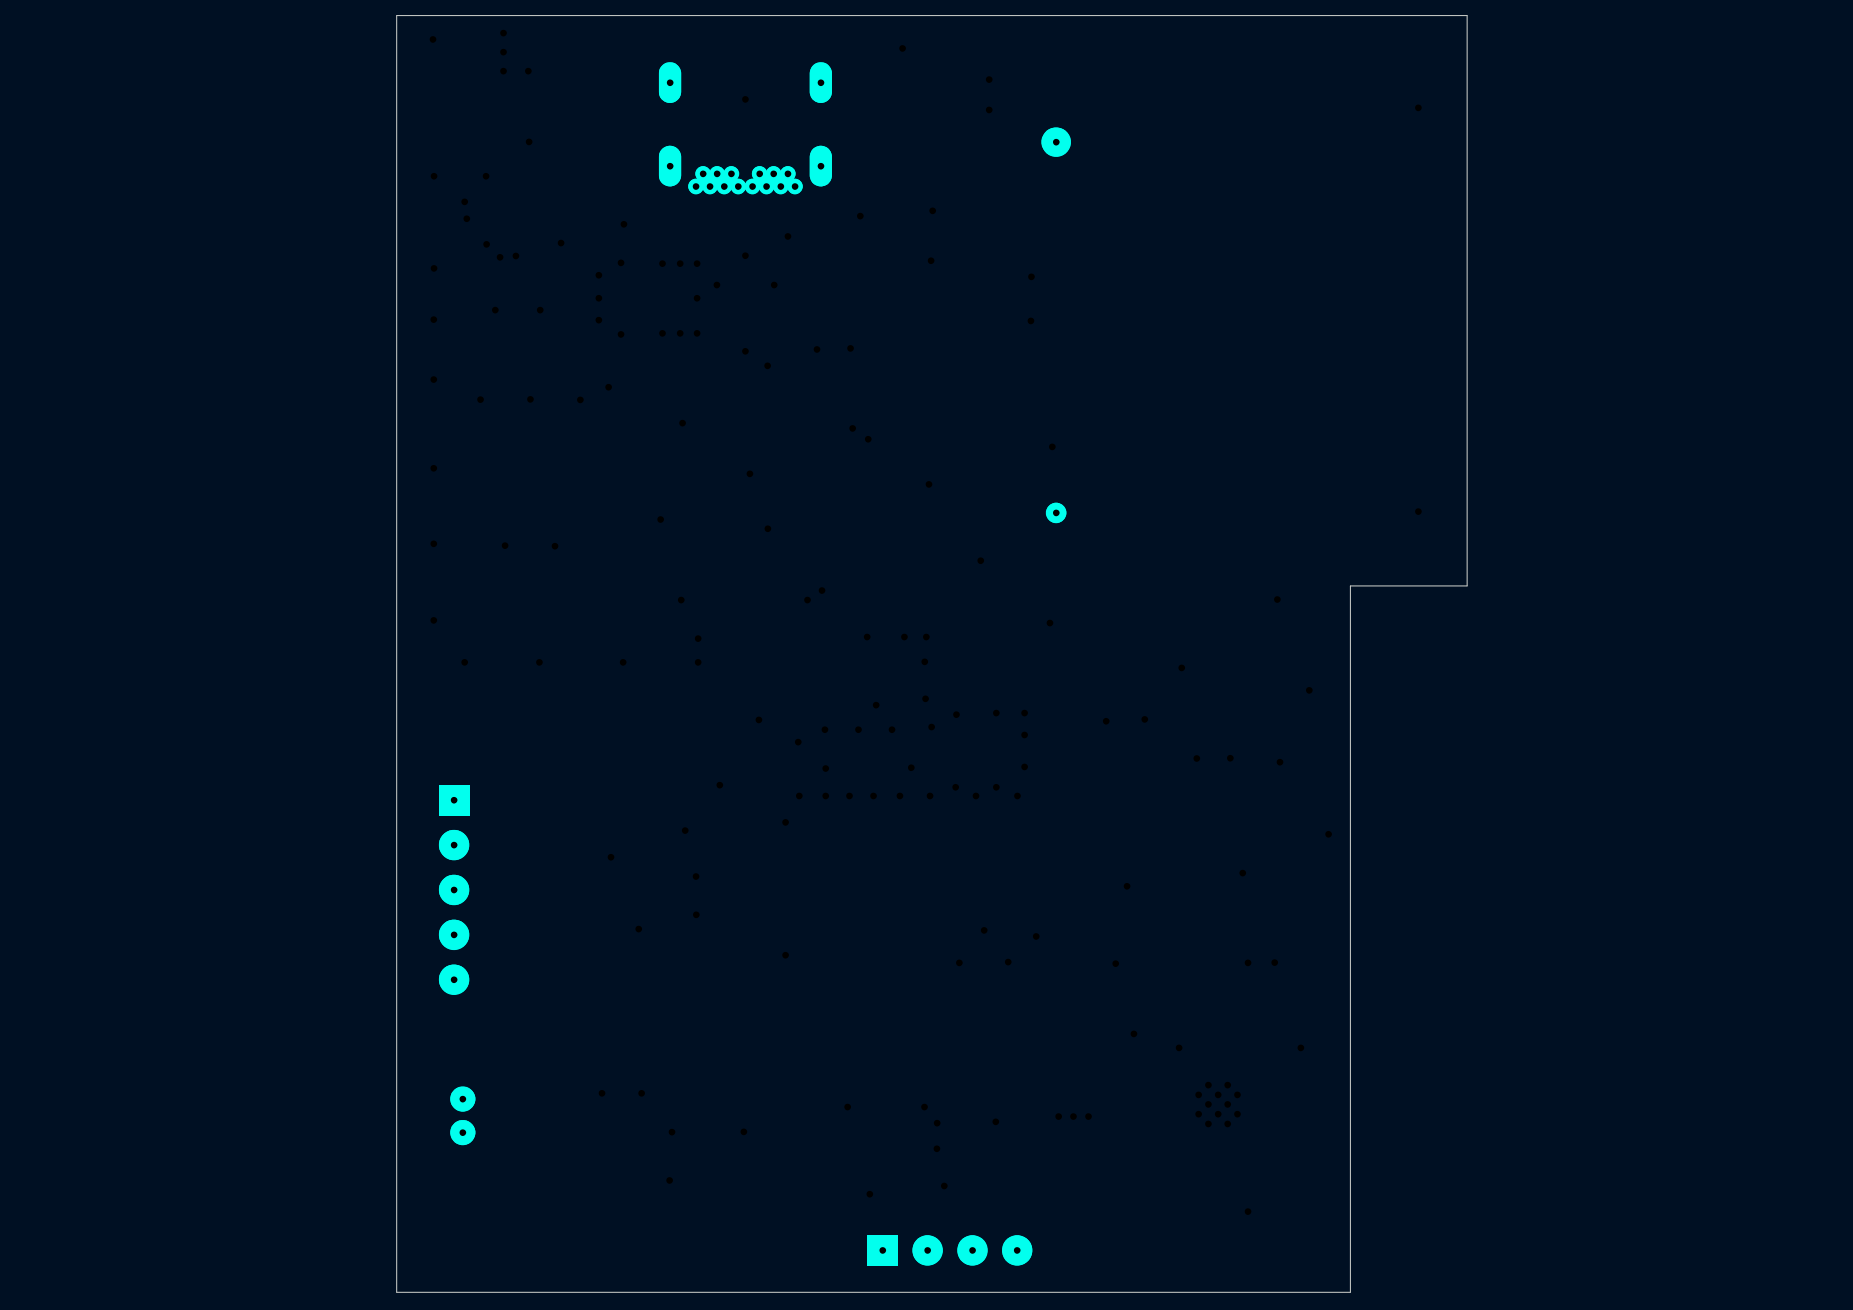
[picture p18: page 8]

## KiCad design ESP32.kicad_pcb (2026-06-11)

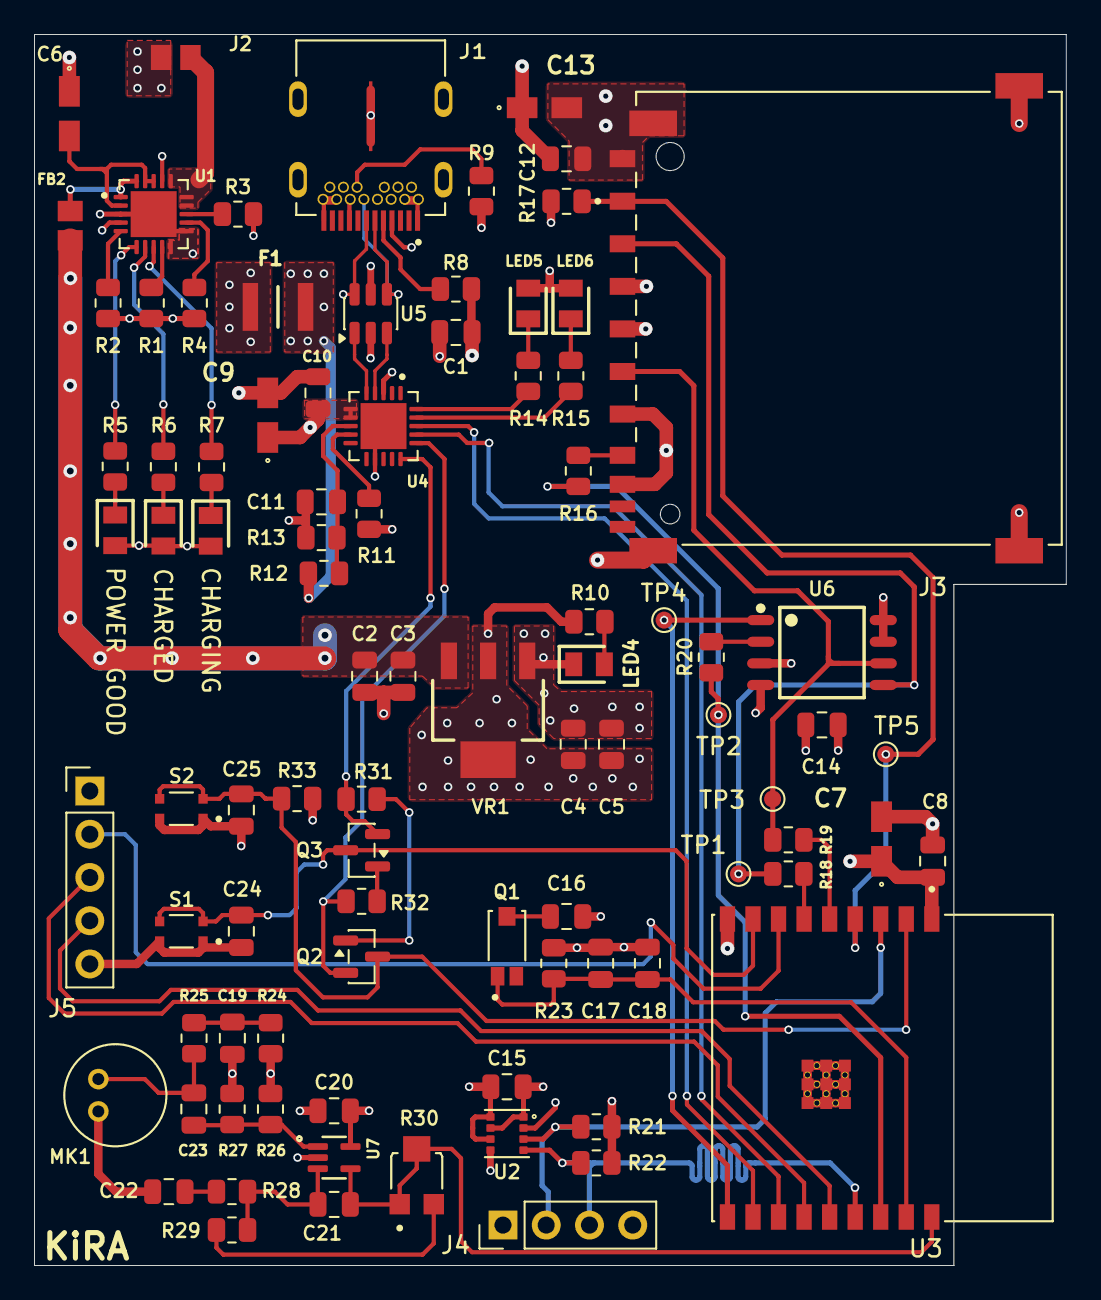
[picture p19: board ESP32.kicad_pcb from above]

Board: 4 copper layers, 60.6 x 72.3 mm, 90 parts (0 on the bottom side), 62 nets.

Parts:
C1, C2, C5, C8, C10, C12, C14, C15, C16, C19, C20, C24: 100nF; C_0805_2012Metric
C3, C4, C22: 10uF; C_0805_2012Metric
C6, C9: 4.7uF; T491A
C7, C13: 10uF; T491A
C11, C25: 1uF; C_0805_2012Metric
C17, C18, C23: 10nF; C_0805_2012Metric
C21: 100pF; C_0805_2012Metric
F1: 0ZCH0110AF2E; FUSC3226X100N
FB2: FBMJ2125HM330-T; BEADC2012X105N
J1: SS-52400-002; BELFUSE_SS-52400-002
J2: B2B-PH-SM4-TB; BEADC2012X105N
J3: GSD090012SEU; AMPHENOL_GSD090012SEU
J4: Conn_01x04_Pin; PinHeader_1x04_P2.54mm_Vertical
J5: Conn_01x05_Pin; PinHeader_1x05_P2.54mm_Vertical
LED1, LED5: LTST-C170GKT; LEDC2012X120N
LED2, LED4, LED6: LTST-C170KRKT; LEDC2012X120N
LED3: LTST-C170TBKT; LEDC2012X120N
MK1: CMC-5042PF-AC; CUI_CMC-5042PF-AC
Q1: TEMT6000X01; TRANS_TEMT6000X01
Q2, Q3: BC817; SOT-23
R1, R2, R17, R23, R31, R32, R33: 10K; R_0805_2012Metric
R3, R24, R25: 2K; R_0805_2012Metric
R4: 20K; R_0805_2012Metric
R5, R6, R7, R10, R14, R15: 470R; R_0805_2012Metric
R8, R9: 5K1; R_0805_2012Metric
R11, R28: 1K; R_0805_2012Metric
R12: 22K1; R_0805_2012Metric
R13: 47K5; R_0805_2012Metric
R16, R18, R19, R20: 50R; R_0805_2012Metric
R21, R22: 4K7; R_0805_2012Metric
R26, R27: 1M; R_0805_2012Metric
R29: 22K; R_0805_2012Metric
R30: 35WR100KLFTR; TRIM_35WR100KLFTR
S1: BOOT; SW_USLPT2819DT2TR
S2: RESET; SW_USLPT2819DT2TR
TP1: Test MOSI; TestPoint_Pad_D1.0mm
TP2: Test MISO; TestPoint_Pad_D1.0mm
TP3: Test SCLK; TestPoint_Pad_D1.0mm
TP4: Test CS; TestPoint_Pad_D1.0mm
TP5: Test CS_SD; TestPoint_Pad_D1.0mm
U1: MCP73871-2CAI_ML; QFN50P400X400X100-21N
U2: BME280; PSON65P250X250X100-8N
U3: ESP32-C3-WROOM-02-H4; MODULE_ESP32-C3-WROOM-02-H4
U4: CP2102N-Axx-xQFN20; QFN50P400X400X100-21N
U5: USBLC6-2SC6; SOT-23-6
U6: W25Q32JVSSIQ; SOIC127P790X216-8N
U7: MAX4466EXK; SOT65P210X110-5N
VR1: LM1117MPX-3.3; VREG_LM1117MPX-3.3

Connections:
+3.3V: C4.1, C5.1, C7.1, C8.1, C9.1, C10.2, C12.1, C13.1, C14.1, C15.1, C16.1, C20.2, J3.4 (VDD1), J4.1, J5.1, LED5.2 (A), LED6.2 (A), R10.1, R11.1, R17.1, R21.2, R22.2, R24.1, R26.1, R33.2, U2.2 (CSB), U2.6 (VDDIO), U2.8 (VDD), U3.1 (3V3), U4.6 (VDD), U4.7 (VREGIN), U6.3 (~WP(IO2)), U6.7 (~HOLD/~RESET(IO3)), U6.8 (VCC), U7.5 (VCC), VR1.2 (VOUT_2), VR1.4 (VOUT_4)
+5V: C2.1, C3.1, FB2.2, VR1.3 (VIN)
/+5V_USB: F1.2, LED1.2 (A), LED2.2 (A), LED3.2 (A), U1.4 (PROG2), U1.17 (CE)
/ESP32-C3-02/BOOT: C24.1, Q3.3 (C), S1.3, S1.4, U3.8 (IO9)
/ESP32-C3-02/CS: TP4.1 (1_1), U3.10 (IO10), U6.1 (~CS)
/ESP32-C3-02/CS_SD: J3.1 (CD/DAT3), R17.2, TP5.1 (1_1), U3.4 (IO5)
/ESP32-C3-02/DTR: Q3.2 (E), R31.1, U4.15 (~CTS)
/ESP32-C3-02/EN: C25.1, Q2.3 (C), R33.1, S2.3, S2.4, U3.2 (EN)
/ESP32-C3-02/GPIO8: J5.2, U3.7 (IO8)
/ESP32-C3-02/GPIO18: J5.3, U3.13 (IO18)
/ESP32-C3-02/GPIO19: J5.4, U3.14 (IO19)
/ESP32-C3-02/MIC_OUT: C21.1, R30.1, R30.2, U3.18 (IO0), U7.4 (OUT)
/ESP32-C3-02/MISO_DO: R16.2, R20.2, TP2.1 (1_1), U3.16 (IO2)
/ESP32-C3-02/MOSI_DI: J3.2 (CMD), R18.2, TP1.1 (1_1), U6.5 (DI(IO0))
/ESP32-C3-02/PHOTO_S: C17.1, C18.1, Q1.1, R23.1, U3.17 (IO1)
/ESP32-C3-02/RTS: Q2.2 (E), R32.1, U4.16 (~RTS)
/ESP32-C3-02/RX_TX: U3.12 (TXD), U4.17 (RXD)
/ESP32-C3-02/SCL: J4.3, R22.1, U2.4 (SCK), U3.15 (IO3)
/ESP32-C3-02/SCLK: J3.5 (CLK), R19.1, TP3.1 (1_1), U6.6 (CLK)
/ESP32-C3-02/SDA: J4.2, R21.1, U2.3 (SDI), U3.3 (IO4)
/ESP32-C3-02/TX_RX: U3.11 (RXD), U4.18 (TXD)
/ESP32-C3-02/USB_DN: U4.5 (D-), U5.1 (I/O1)
/ESP32-C3-02/USB_DP: U4.4 (D+), U5.3 (I/O2)
/USB_D+: J1.A6 (DP1), J1.B6 (DP2), U5.4 (I/O2)
/USB_D-: J1.A7 (DN1), J1.B7 (DN2), U5.6 (I/O1)
/VBAT: J2.2, U1.14 (VBAT), U1.15 (VBAT), U1.16 (VBAT_SENSE)
/VBUS: C1.1, F1.1, J1.A4 (VBUSA1), J1.A9 (VBUSA2), J1.B4 (VBUSB1), J1.B9 (VBUSB2), R12.1, U5.5 (VBUS)
GND: C1.2, C2.2, C3.2, C4.2, C5.2, C6.1, C7.2, C8.2, C9.2, C10.1, C11.2, C12.2, C13.2, C14.2, C15.2, C17.2, C18.2, C19.1, C20.1, C22.1, C24.2, C25.2, J1.A1 (GNDA1), J1.A12 (GNDA2), J1.B1 (GNDB1), J1.B12 (GNDB2), J1.G1 (GND/SHIELD), J1.G2 (GND/SHIELD), J1.G3 (GND/SHIELD), J1.G4 (GND/SHIELD), J1.S1 (GND/SHIELD), J1.S2 (GND/SHIELD), J1.S3 (GND/SHIELD), J1.S4 (GND/SHIELD), J2.1, J3.3 (VSS1), J3.6 (VSS2), J3.8 (DAT1), J3.9 (DAT2), J3.G1 (SHIELD_GND), J3.G2 (SHIELD_GND), J3.G3 (SHIELD_GND), J3.G4 (SHIELD_GND), J4.4, J5.5, LED4.1 (K), MK1.GND, R1.1, R2.2, R3.2, R4.2, R8.1, R9.1, R13.2, R23.2, R27.2, S1.1, S1.2, S2.1, S2.2, U1.3 (SEL), U1.10 (VSS), U1.11 (VSS), U1.21 (VSS), U2.1 (GND), U2.5 (SDO), U2.7 (GND), U3.9 (GND), U3.19 (GND), U3.20 (GND), U3.21 (GND), U3.22 (GND), U3.23 (GND), U3.24 (GND), U3.25 (GND), U3.26 (GND), U3.27 (GND), U3.28 (GND), U3.29 (GND), U3.30 (GND), U3.31 (GND), U3.32 (GND), U3.33 (GND), U3.34 (GND), U3.35 (GND), U3.36 (GND), U3.37 (GND), U3.38 (GND), U3.39 (GND), U4.3 (GND), U4.12 (GND), U4.21 (GND), U5.2 (GND), U6.4 (GND), U7.2 (GND), VR1.1 (GND)
unnamed: C16.2, Q1.3
unnamed: C19.2, R24.2, R25.1
unnamed: C22.2, R28.2
unnamed: C23.1, MK1.OUT, R25.2
unnamed: FB2.1, U1.1 (OUT), U1.20 (OUT)
unnamed: J1.A5 (CC1), R8.2
unnamed: J1.B5 (CC2), R9.2
unnamed: J3.7 (DAT0), R16.1
unnamed: LED1.1 (K), R6.1
unnamed: LED2.1 (K), R7.1
unnamed: LED3.1 (K), R5.1
unnamed: LED4.2 (A), R10.2
unnamed: LED5.1 (K), R14.1
unnamed: LED6.1 (K), R15.1
unnamed: Q2.1 (B), R31.2
unnamed: Q3.1 (B), R32.2
unnamed: R29.2, R30.3
unnamed: R3.1, U1.13 (PROG1)
unnamed: R4.1, U1.12 (PROG3)
unnamed: R7.2, U1.8 (STAT1/~LBO)
unnamed: R6.2, U1.7 (STAT2)
unnamed: R2.1, U1.5 (THERM)
unnamed: C6.2, U1.2 (VPCC), U1.18 (IN), U1.19 (IN)
unnamed: R5.2, U1.6 (~PG)
unnamed: R1.2, U1.9 (~TE)
unnamed: R19.2, U3.5 (IO6)
unnamed: R18.1, U3.6 (IO7)
unnamed: C11.1, R12.2, R13.1, U4.8 (VBUS)
unnamed: R11.2, U4.9 (~RST)
unnamed: R15.2, U4.19 (~RXT/GPIO.3)
unnamed: R14.2, U4.20 (~TXT/GPIO.2)
unnamed: R20.1, U6.2 (DO(IO1))
unnamed: C23.2, R26.2, R27.1, U7.1 (IN+)
unnamed: C21.2, R28.1, R29.1, U7.3 (IN-)
